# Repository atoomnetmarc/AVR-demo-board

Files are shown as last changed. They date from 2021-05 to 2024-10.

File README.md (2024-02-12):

# AT90S1200

Demo board for the 20-pin AT90S1200 and AT90S2313 microcontroller.

Yes these chips are old, Arduino was not a thing back then. The AT90S1200 on the pcb is my first microcontroller I bought and programmed. It has a date code of 1998 week 40. I wrote software for it using AVR studio (4?) in assembler and programmed it using the [Handyman programmer and software made by Elektor](https://www.elektormagazine.com/magazine/elektor-199712/33974).

This AT90S1200 has only ever been used in breadboards, now about 20 years later it got its own PCB.

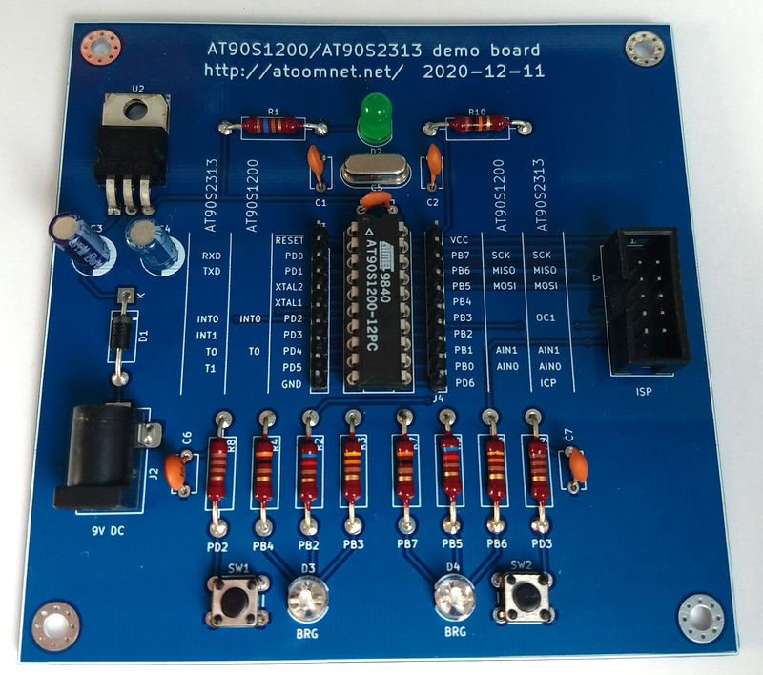
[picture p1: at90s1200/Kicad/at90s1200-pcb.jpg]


Like the silkscreen pinout? [Here](AVR%20overview.md) is a complete(-ish) overview of all know pin-compatible AT90S* microcontrollers and their pin functions.

# AT90S2323

The AT90S2323 is a 8-pin microcontroller with a whopping 3 I/O-pins. I believe this is the first 8-pin AVR.

One day I found some on eBay, bought them and proceeded to created this demo board to show its capabilities. I figured to control 128 LEDs with 3 I/O-pins. To expand de 3 I/O to drive 128 LEDs I used 3 shift registers in a 16x8 configuration. The shift registers however need 4 signals to drive them: DATA, CLK, RCLK and OE. When I tied RCLK and OE together I could bring that down to 3.

https://user-images.githubusercontent.com/48124268/116798381-1cadf400-aaef-11eb-9674-959b9dbc6236.mp4

# AT90S8535

The AT90S8535 belongs to the first 40-pin AVR microcontrollers from Atmel together with the AT90S8515. There also existed a 4K flash version of this chip, but that version seems to be only short lived, if at all.

This board breaks out all pins of the microcontroller into mostly PMOD compatible connectors. Mostly because if I understand correctly the voltage for PMOD IO and VCC should normally be at 3.3V. This board has both 5V and 3.3V PMOD connectors.

All pin-compatible microcontrollers will fit. When using a ATmega163 or newer, J8 is useable as a 5V I2C PMOD connector. When using a ATmega8535, J5 can be used as a 3.3V HW SPI PMOD port. When using ATmega323 or newer, EXP can be used as a JTAG connector.

On the back of the PCB there is a SOT-23 voltage monitor that functions as a BOD (brow out detector). Unlike newer parts, the AT90S8535 does not have a onboard BOD.

More information about this board: [README.md](at90s8535/README.md)

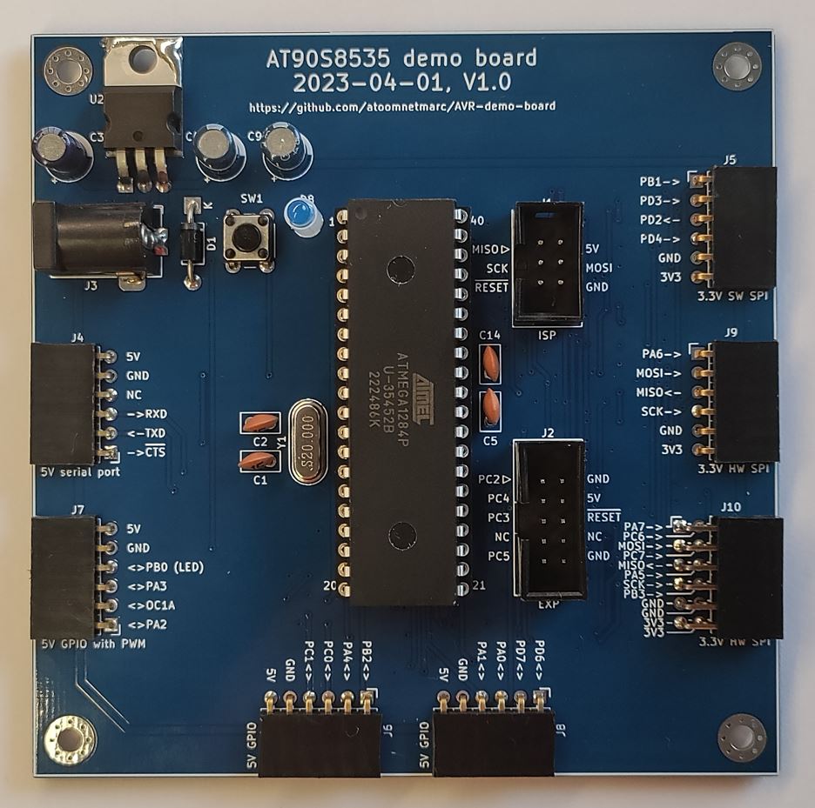
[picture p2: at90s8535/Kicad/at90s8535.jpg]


# Programming vintage AVRs in 2023

## Programmer

Make a [Arduino-as-ISP-shield](https://github.com/atoomnetmarc/Arduino-as-ISP-shield), then use AVRDUDE or [AVRDUDESS](https://blog.zakkemble.net/avrdudess-a-gui-for-avrdude/) to program the .hex file. This works under Windows 10.

AVRDUDE 6.3 is unable to program the AT90S2323 because it wrongly assumes this chip is the same as a AT90S2343, but it is not. Edit avrdude.conf and add the contents of [avrdude-at90s2323.conf](avrdude-at90s2323.conf) to just below the AT90S2343 config. This new section is a copy of the AT90S2343 section with one change, the chip signature.

## AVR Studio 4.19

Use the ancient [AVR Studio v4.19.730](https://www.microchip.com/mplab/avr-support/avr-and-sam-downloads-archive) to compile programs for the old AT90S* AVR's.

To compile c-programs you can still use [WinAVR-20100110-install.exe](https://sourceforge.net/projects/winavr/files/WinAVR/20100110/) containing ~~an old~~ a mature GCC compiler versioned 4.3, but you need some to [fix some incompatibilities with Windows 10](https://www.avrfreaks.net/s/topic/a5C3l000000USrIEAW/t124726) in order to make it work.\
There is a simpler solution, just use an [updated GCC](https://blog.zakkemble.net/avr-gcc-builds/). This update contains GCC version 12 and works to compile programs for the old AT90S* chips in AVR Studio 4.19.

## Visual Studio Code + PlatformIO

I was pleasantly surprised to find out that compiling a c-program using VSCode and PlatformIO also is a viable option. See the firmware directory of the AT90S2323 for an example on how to configure PlatformIO or see [the PlatformIO example native-blink](https://github.com/platformio/platform-atmelavr/tree/develop/examples/native-blink).

It is also possible to program the AT90S1200 in VSCode with PlatformIO in assembler! Have a look at my PlatformIO [blink](at90s1200/Firmware/blink/) project. You could also program the ATtiny2313 with the same assembler (and some `#if defined` macros) and debug using Microchip Studio.



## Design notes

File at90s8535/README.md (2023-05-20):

# MightyCore

You could use [MightyCore](https://github.com/MCUdude/MightyCore) to program a supported MCU (ATmega8535, ATmega16, ATmega32, ATmega164, ATmega324, ATmega644 and ATmega1284) using Arduino IDE or PlatformIO.

To be useful as an Arduino board, you must first burn a bootloader using the Arduino IDE. Use the instructions from the [MightyCore GitHub page](https://github.com/MCUdude/MightyCore) to burn the bootloader.

Verify the bootloader burn by compiling the blink sketch and uploading it to the board using the [USB UART PMOD](https://github.com/atoomnetmarc/PMOD-USB-UART) (or your own compatible serial cable). After uploading LED D8 should blink.

# AT90S4434 or AT90S8535

These old MCUs do not have bootloader capability and are not supported by [MightyCore](https://github.com/MCUdude/MightyCore). Program these with a AVR programmer connected to the ISP header.

# ATmega163 or ATmega323

The ATmega163 and ATmega323 are also not supported by [MightyCore](https://github.com/MCUdude/MightyCore). These MCUs do contain bootloader capability but are not supported by [Optiboot](https://github.com/Optiboot/optiboot).

At this moment (2023-05) you can program these just like the AT90S8535 using the ISP header.

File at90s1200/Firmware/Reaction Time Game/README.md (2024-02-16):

# Reaction Time Game

2 players battle for the fastest reaction time. Game automatically starts when MCU is powered on. Players must press button when blue LED turn off. This will happen after a random amount of time.

The fastest reaction time is indicated by a few seconds of green LED. Slowest reaction time is indicated by red LED. When somehow both players are equally fast, because buttons are samples 1000 times a second, then both get green LED. When no reaction was given, both get red LED. Pressed too early? Red.

Randomness is generated when a button is pressed.

State machine:\


This game was specifically written in gcc assembly for the RAM-less AT90S1200, but also made working on pin-compatible newer AVR parts.

| MCU | tested? |
| -- | -- |
| AT90S1200 | :ballot_box_with_check: |
| AT90S2313 | :ballot_box_with_check: |
| ATtiny2313 | :ballot_box_with_check: |
| ATtiny2313A | :black_square_button: |
| ATtiny4313 | :black_square_button: |



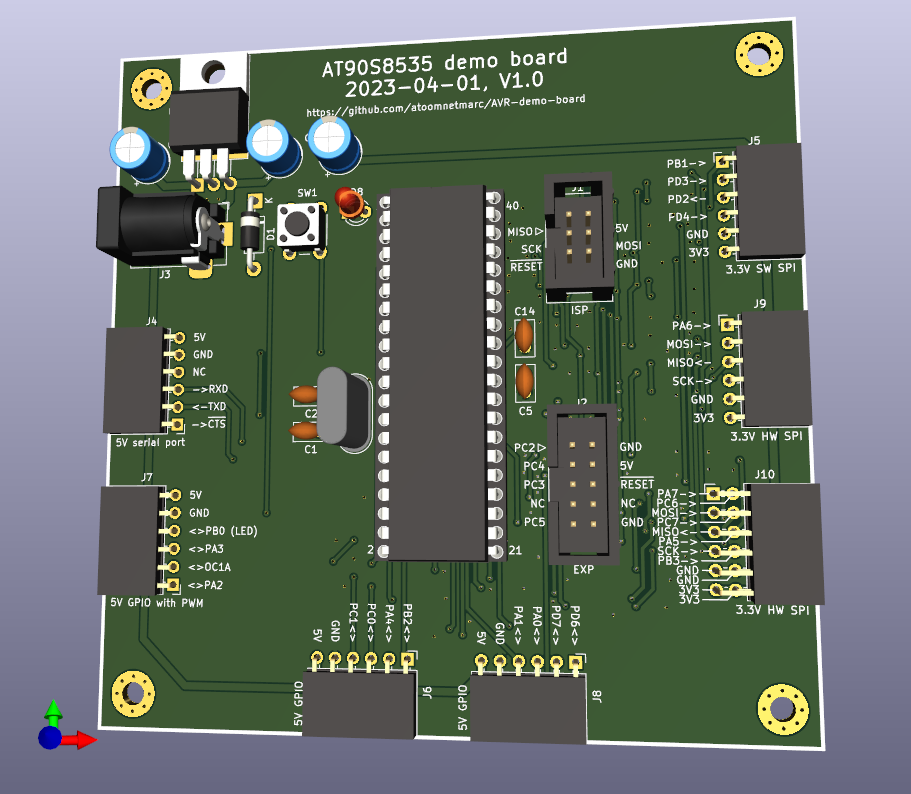
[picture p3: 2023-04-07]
at90s8535/Kicad/at90s8535-render.png

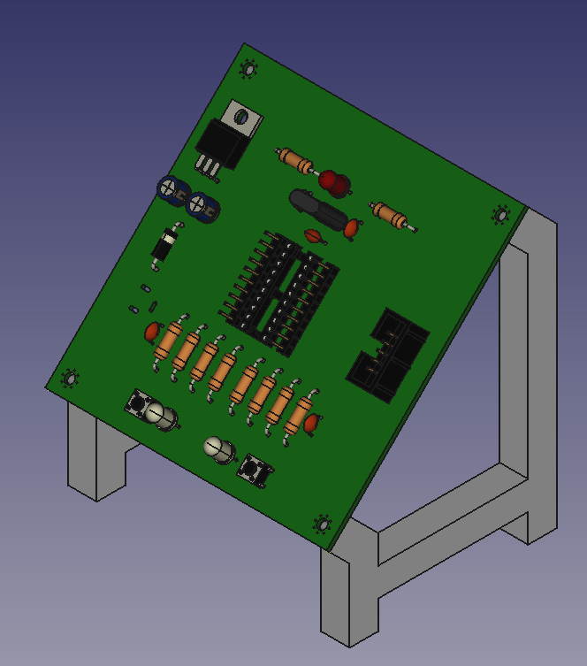
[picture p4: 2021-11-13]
at90s1200/3d/presentation stand.png

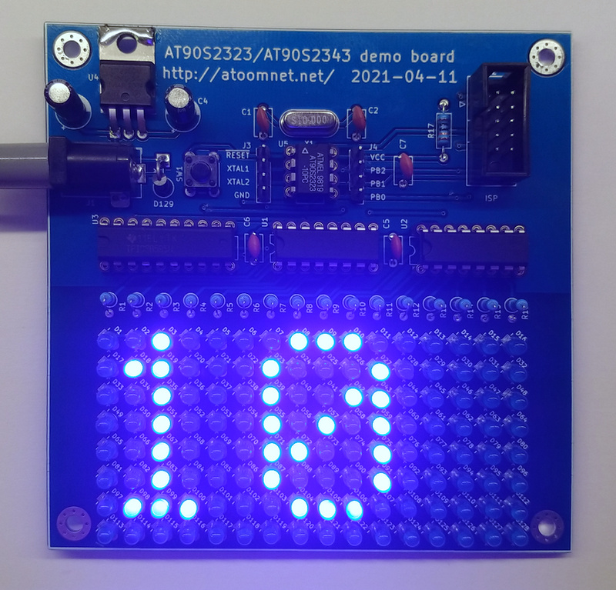
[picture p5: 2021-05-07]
at90s2323/Kicad/at90s2323-pcb.jpg

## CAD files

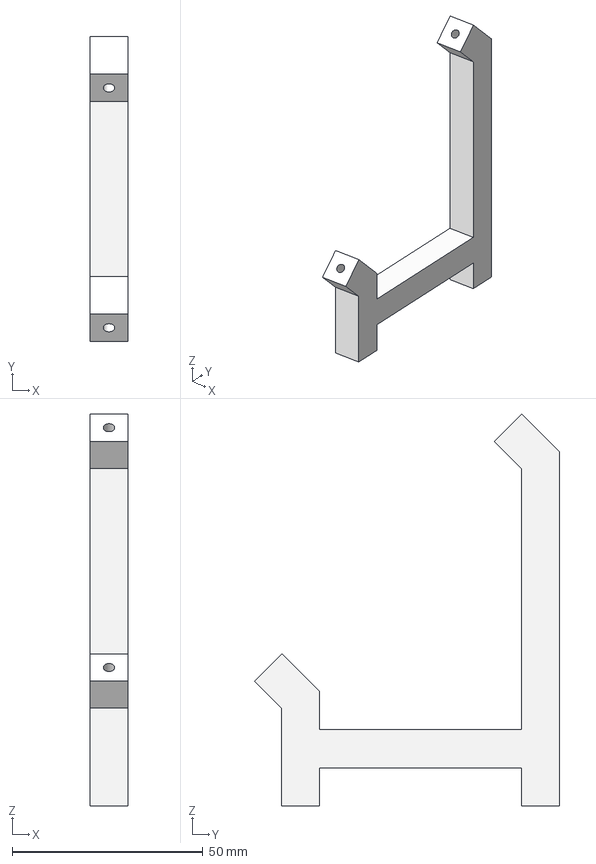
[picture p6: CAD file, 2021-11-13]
at90s1200/3d/presentation stand.step
10.0 x 79.9 x 102.7 mm

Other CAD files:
at90s1200/3d/presentation stand.FCStd
at90s1200/3d/presentation stand.stl

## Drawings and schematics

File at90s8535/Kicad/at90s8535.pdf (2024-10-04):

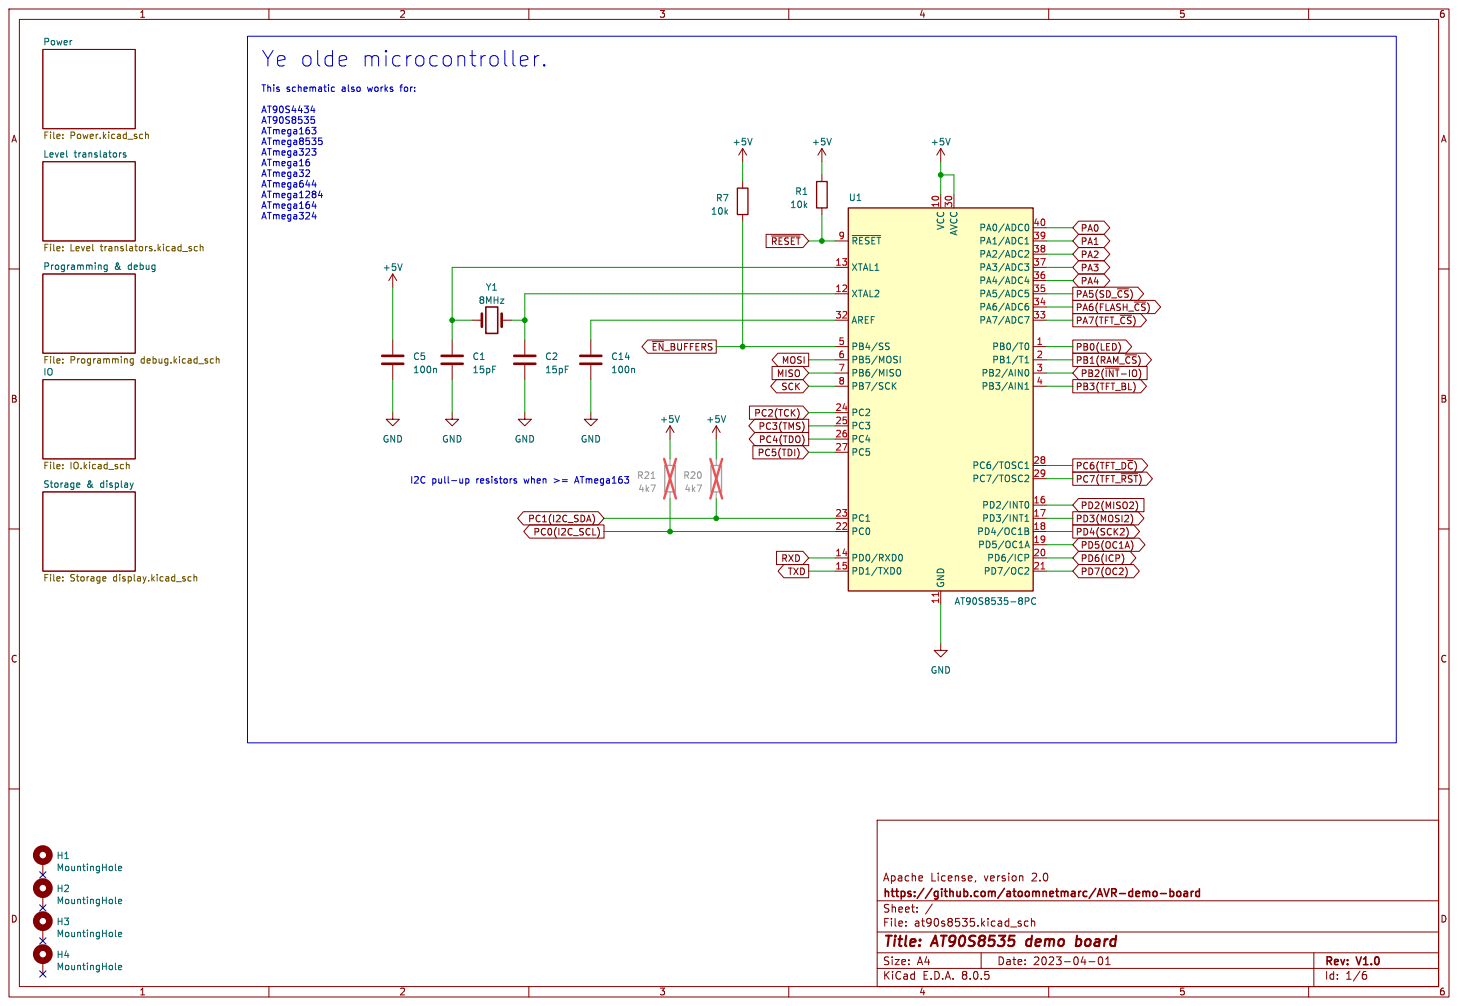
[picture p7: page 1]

PA6(FLASH_~{CS}) TXD Ye olde microcontroller.

Storage & display File: Storage display.kicad_sch

H2 MountingHole H3 MountingHole H1 MountingHole H4 MountingHole

Apache License, version 2.0
File: at90s8535.kicad_sch Sheet: / https://github.com/atoomnetmarc/AVR-demo-board

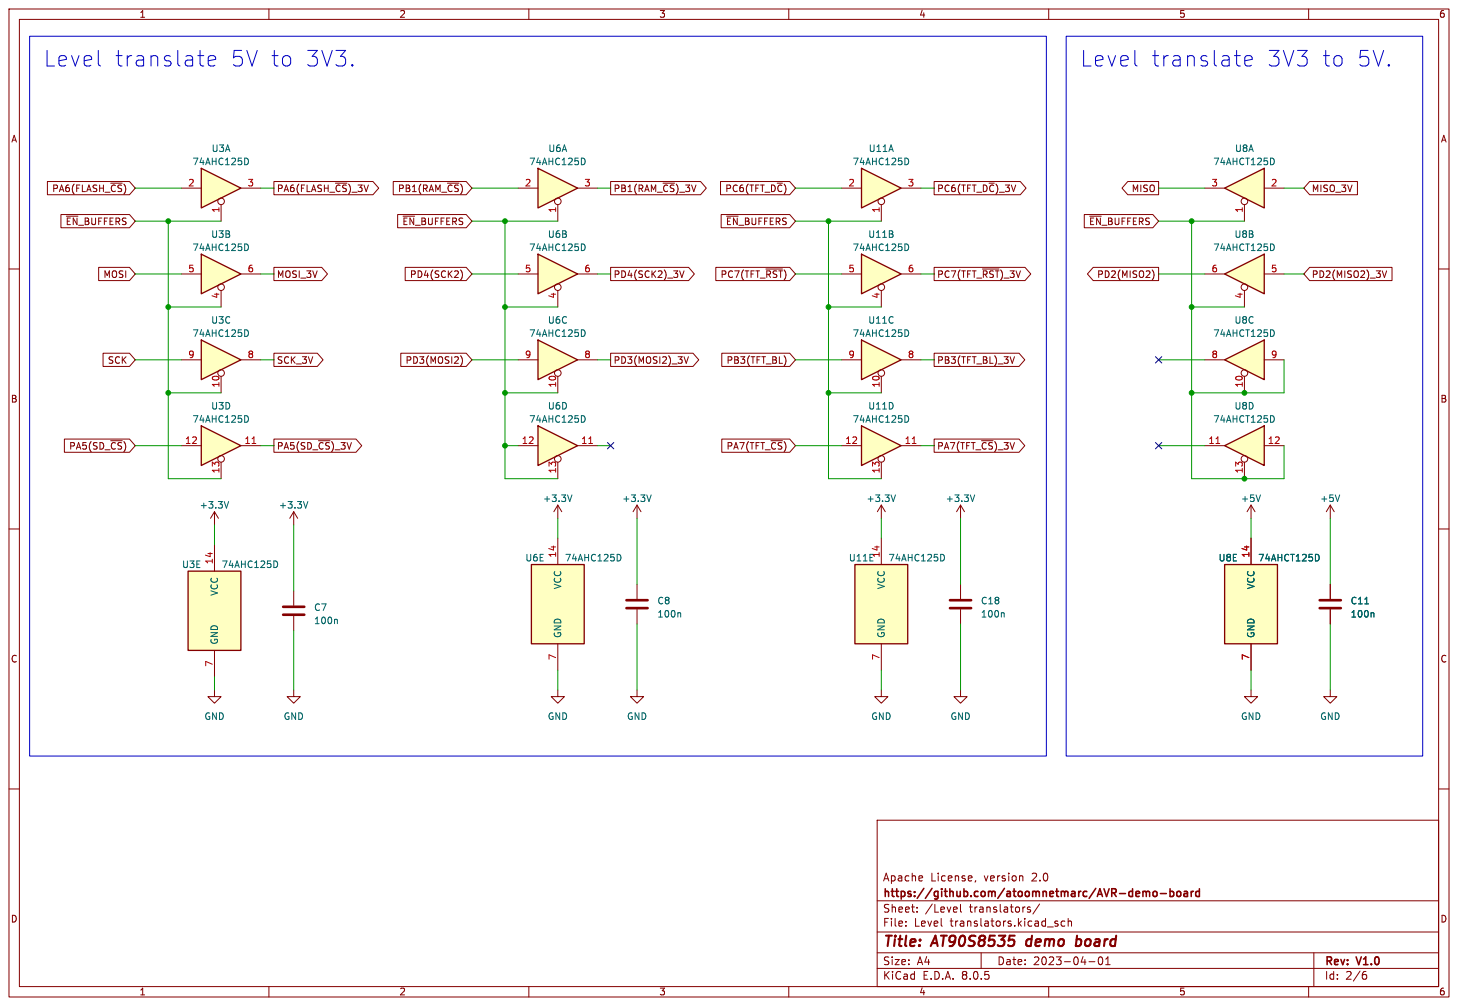
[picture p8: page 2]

Apache License, version 2.0 GND VCC 14 GND

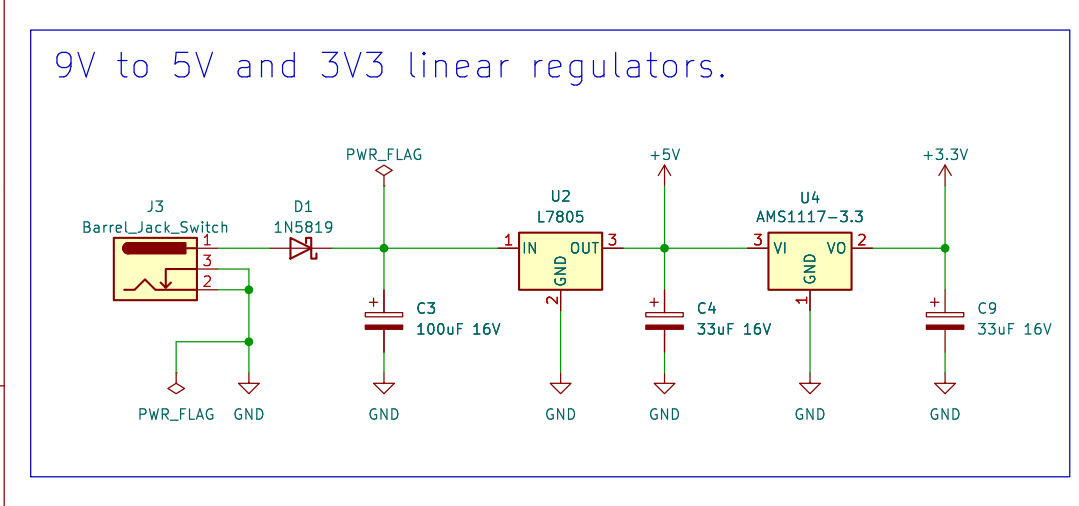
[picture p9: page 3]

1 VO 2 VI 3 U4 AMS1117-3.3 PWR_FLAG +3.3V GND GND

Apache License, version 2.0
File: Power.kicad_sch Sheet: /Power/ https://github.com/atoomnetmarc/AVR-demo-board

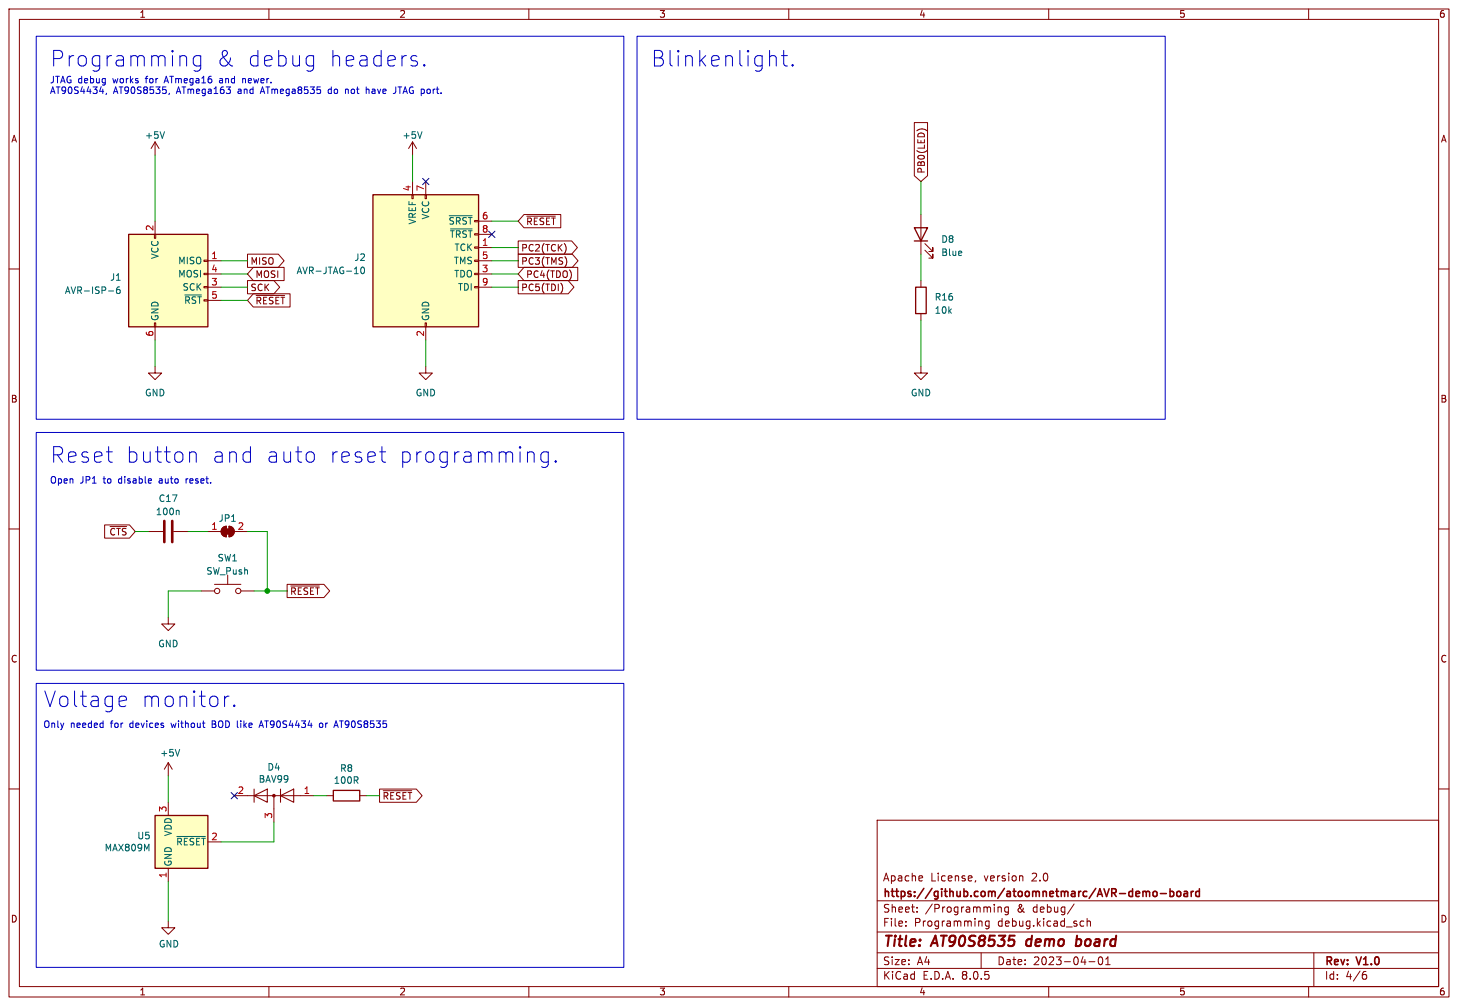
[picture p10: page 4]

2 SCK 3 MOSI 4 ~{RST}5 GND

Open JP1 to disable auto reset.

Only needed for devices without BOD like AT90S4434 or AT90S8535

Apache License, version 2.0
https://github.com/atoomnetmarc/AVR-demo-board

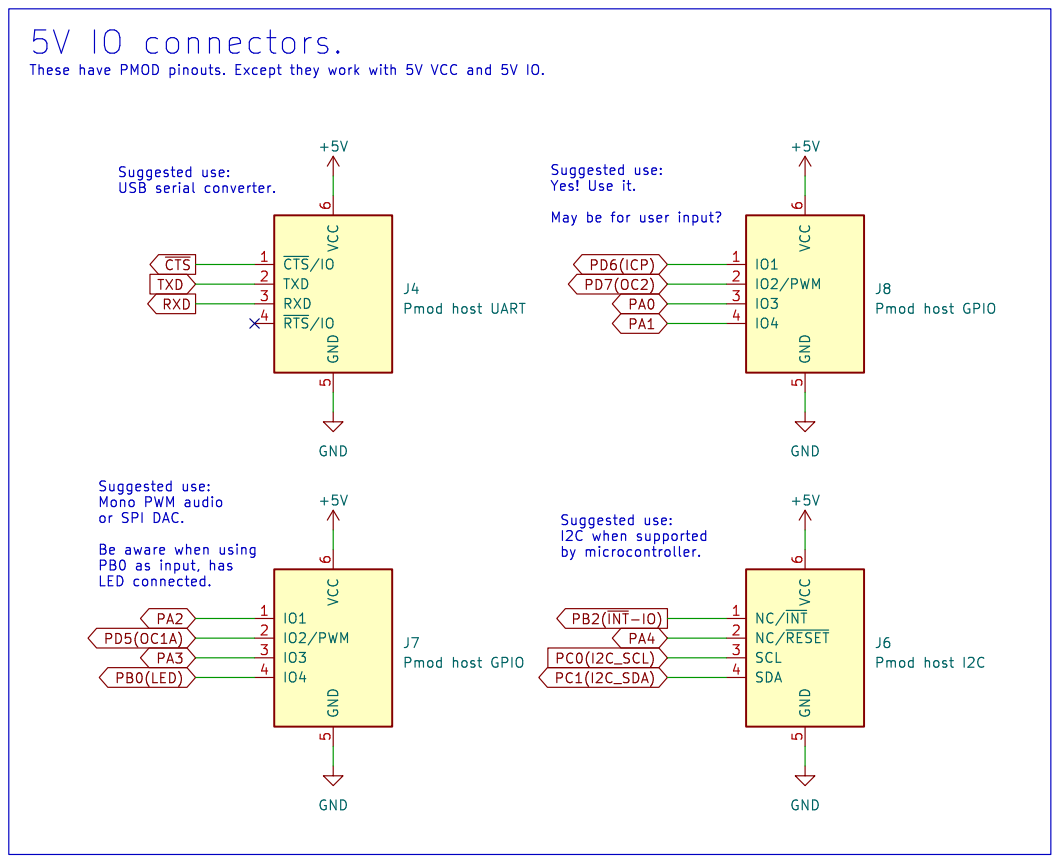
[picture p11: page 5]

Suggested use: Yes! Use it. May be for user input?

Suggested use: Mono PWM audio

Apache License, version 2.0
File: IO.kicad_sch Sheet: /IO/ https://github.com/atoomnetmarc/AVR-demo-board

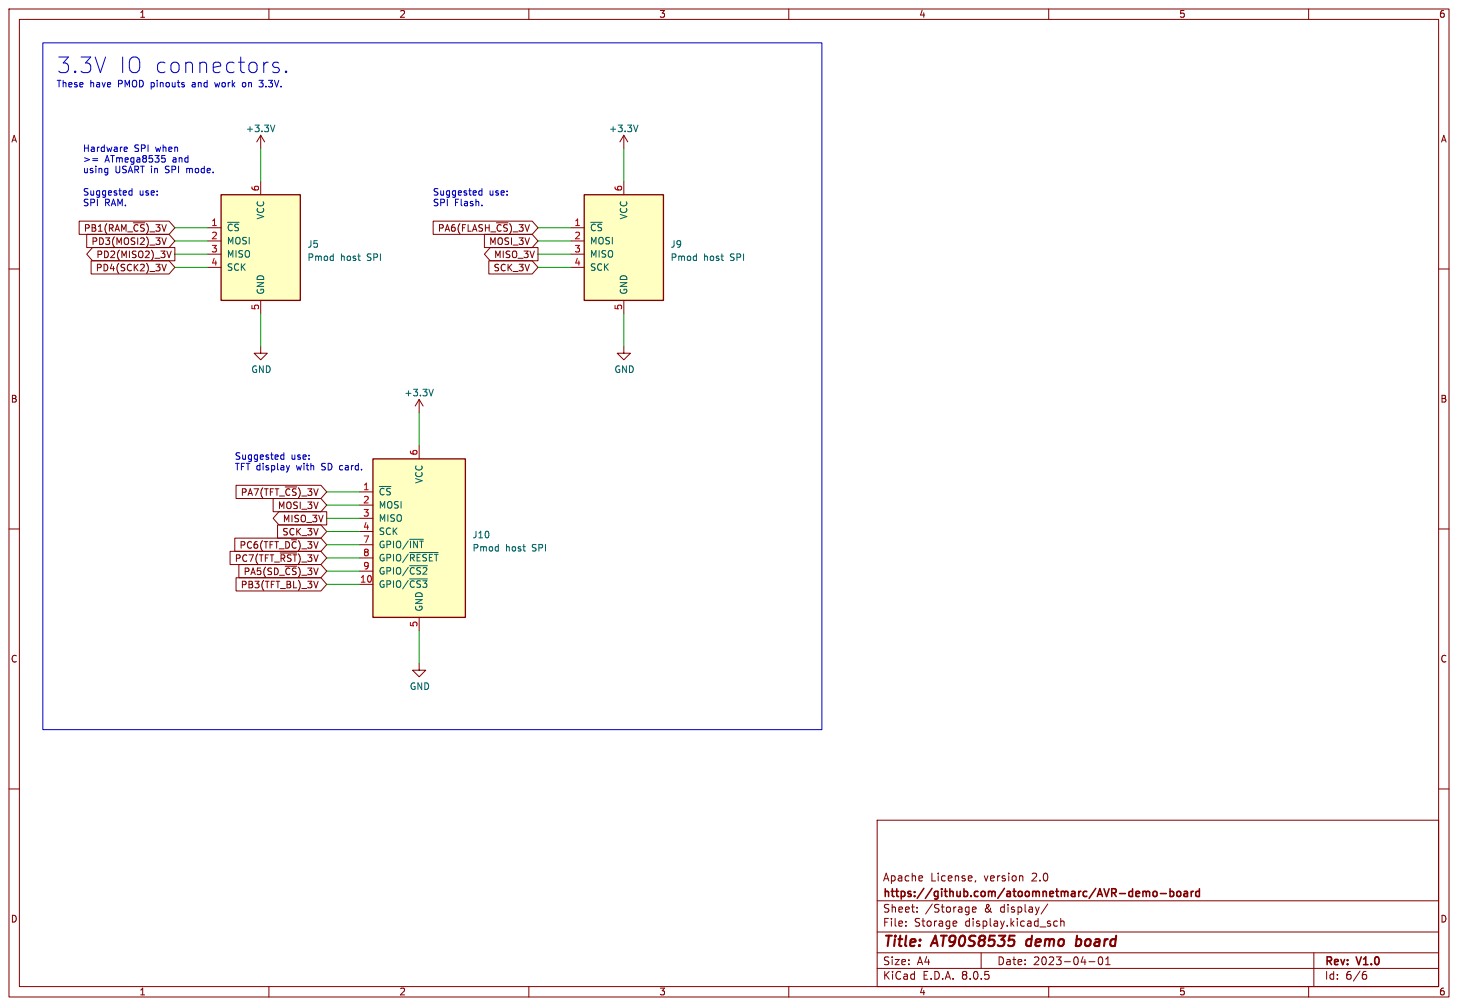
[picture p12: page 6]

using USART in SPI mode. 3.3V IO connectors.

6 GPIO/~{INT} 7 GPIO/~{RESET} 8 GPIO/~{CS2} 9

Apache License, version 2.0
https://github.com/atoomnetmarc/AVR-demo-board

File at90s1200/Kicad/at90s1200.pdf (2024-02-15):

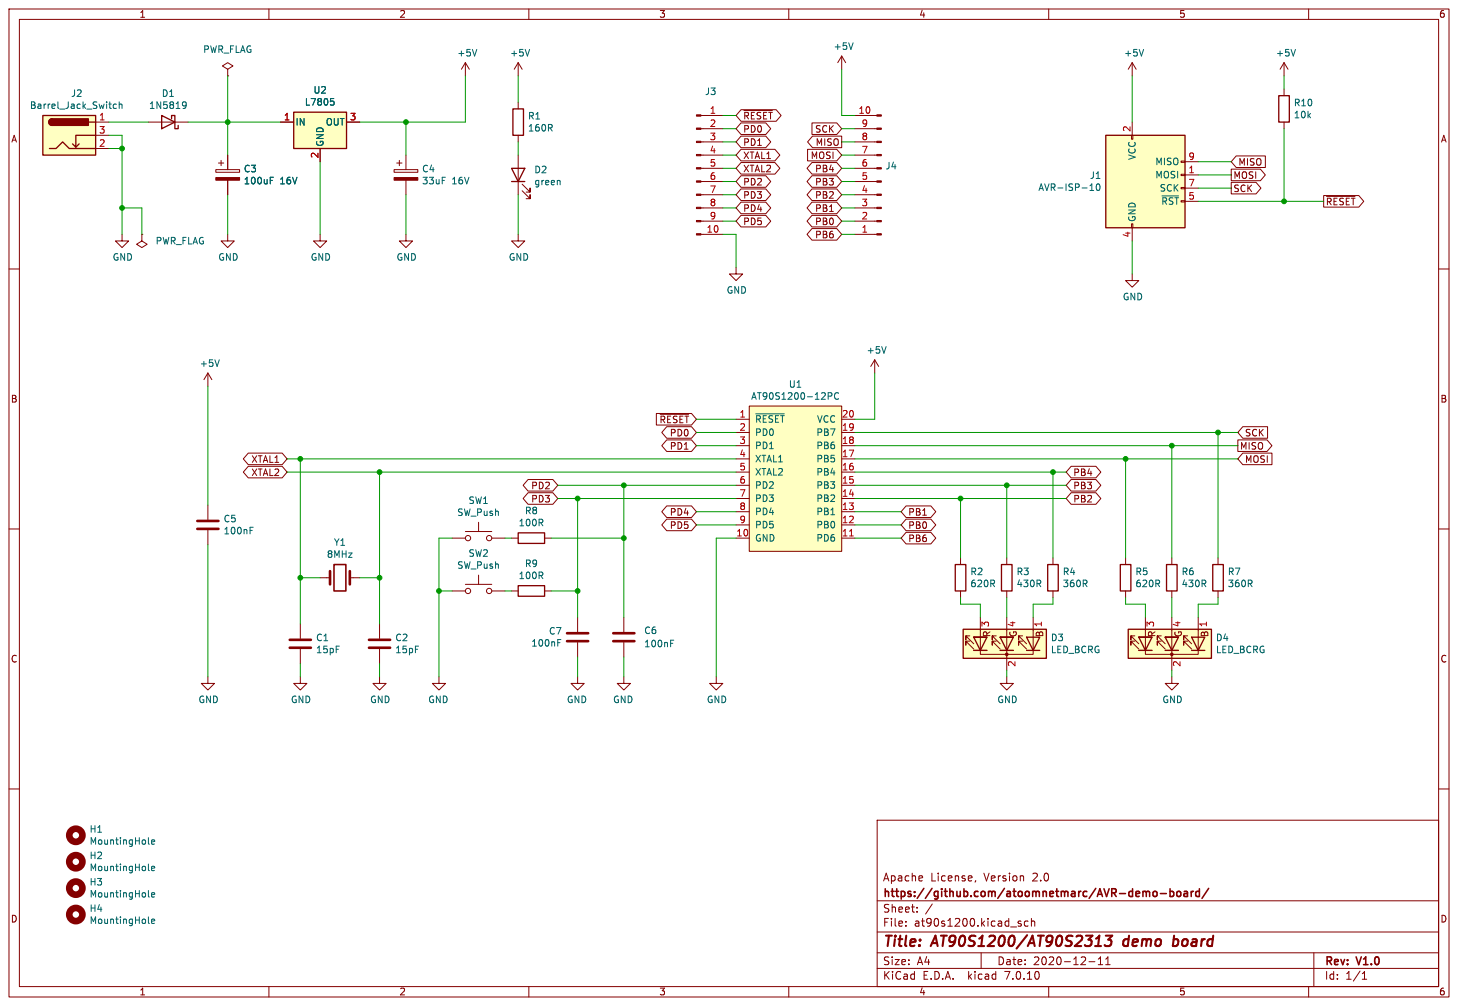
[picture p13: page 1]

Apache License, Version 2.0
File: at90s1200.kicad_sch Sheet: / https://github.com/atoomnetmarc/AVR-demo-board/

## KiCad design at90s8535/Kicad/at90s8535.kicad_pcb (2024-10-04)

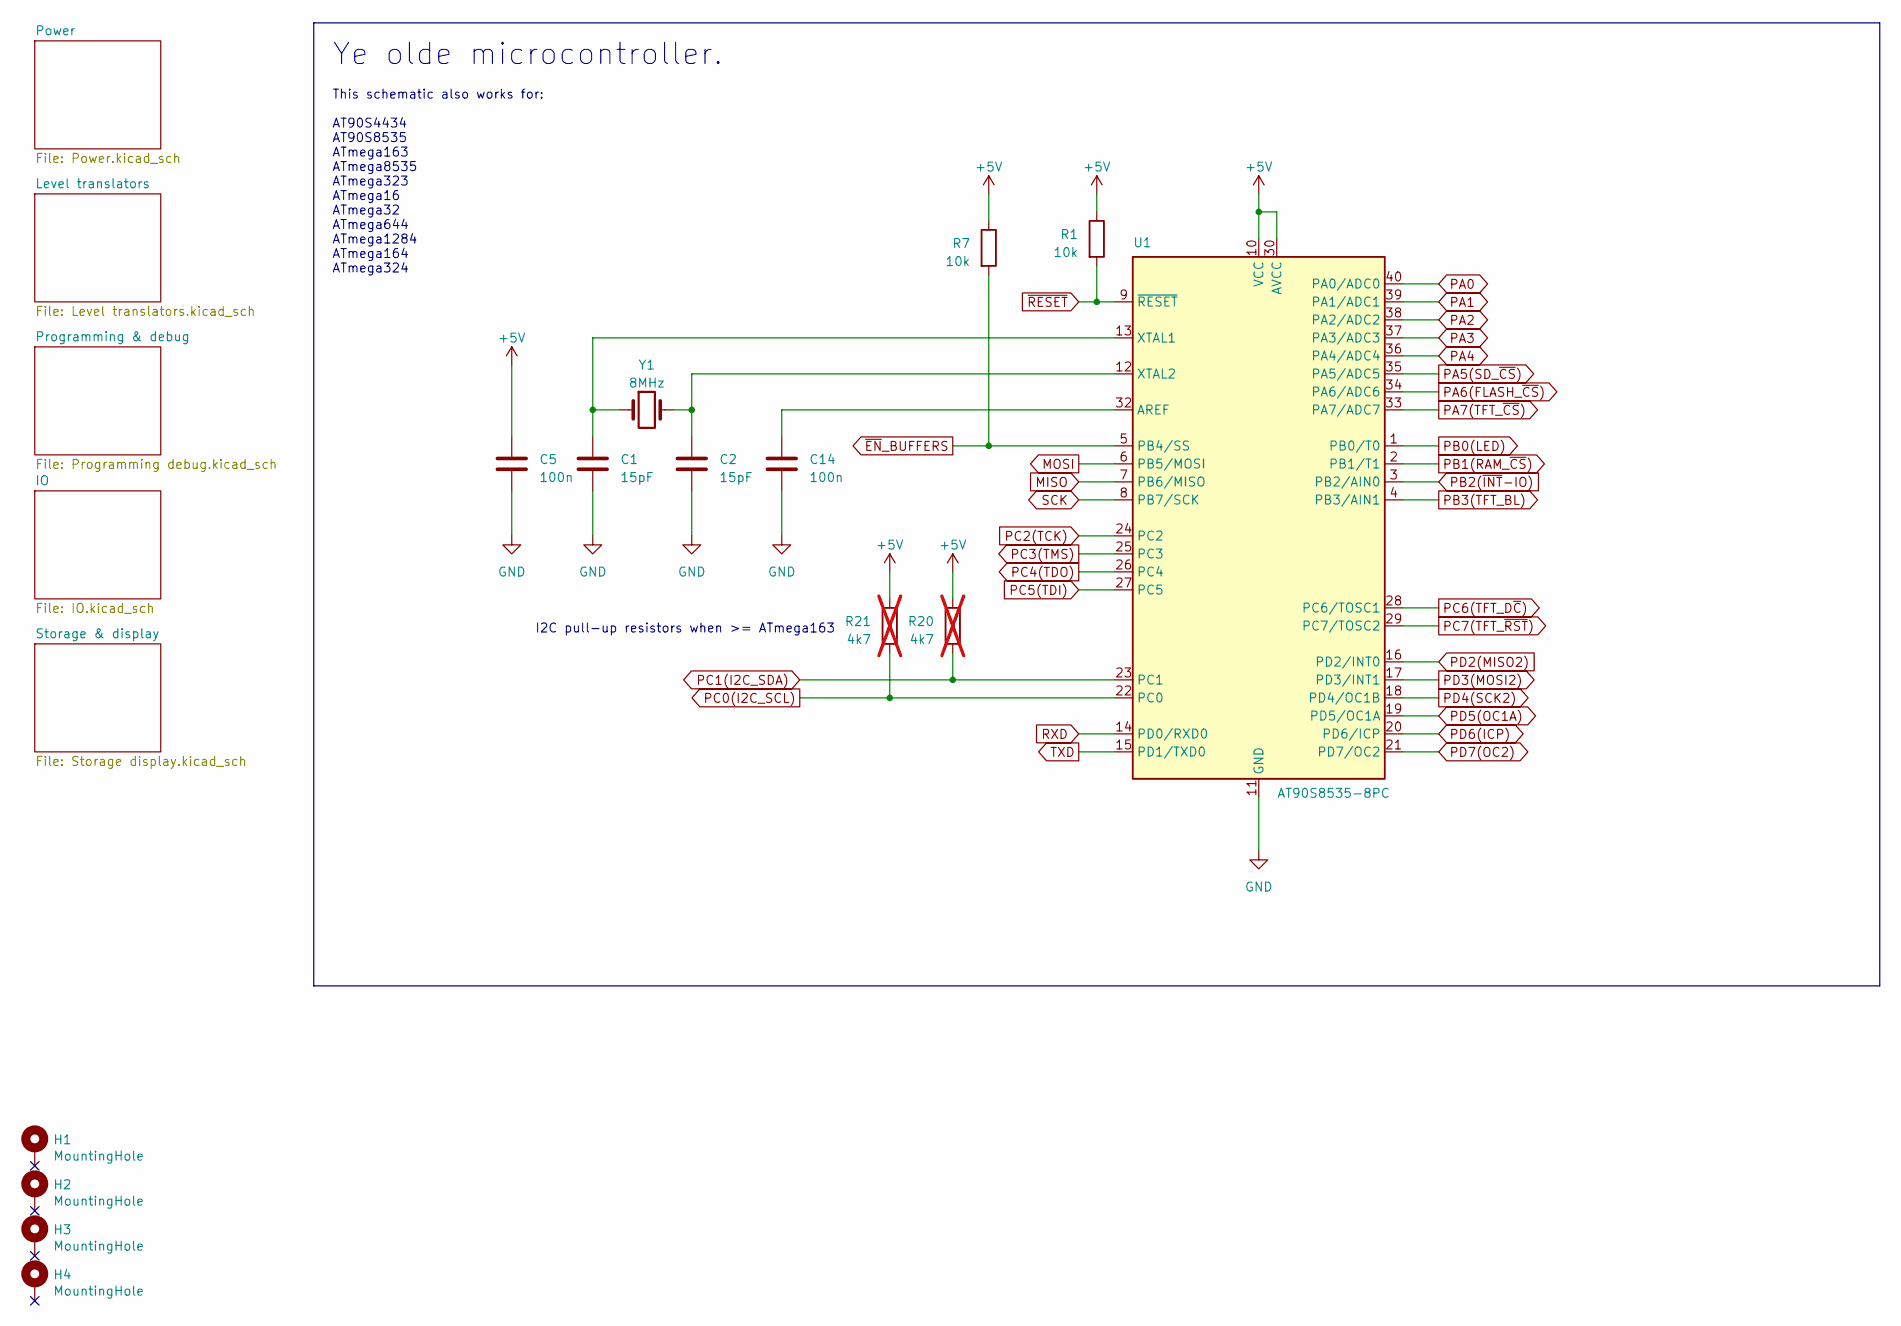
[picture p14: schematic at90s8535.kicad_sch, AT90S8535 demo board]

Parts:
C1, C2: 15pF; C_Disc_D5.0mm_W2.5mm_P2.50mm
C5, C14: 100n; C_Disc_D5.0mm_W2.5mm_P2.50mm
H1, H2, H3, H4: MountingHole; MountingHole_3.2mm_M3_Pad_Via
R1, R7: 10k; R_0805_2012Metric_Pad1.20x1.40mm_HandSolder
R20, R21: 4k7; R_0805_2012Metric_Pad1.20x1.40mm_HandSolder; not fitted
U1: AT90S8535-8PC; DIP-40_W15.24mm
Y1: 8MHz; Crystal_HC49-U_Vertical

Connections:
MISO: U1.7 (PB6/MISO); also elsewhere on the board
MOSI: U1.6 (PB5/MOSI); also elsewhere on the board
unnamed: C14.1, U1.32 (AREF)
unnamed: C1.1, U1.13 (XTAL1), Y1.1
unnamed: C2.1, U1.12 (XTAL2), Y1.2
PA0: U1.40 (PA0/ADC0); also elsewhere on the board
PA1: U1.39 (PA1/ADC1); also elsewhere on the board
PA2: U1.38 (PA2/ADC2); also elsewhere on the board
PA3: U1.37 (PA3/ADC3); also elsewhere on the board
PA4: U1.36 (PA4/ADC4); also elsewhere on the board
PA5(SD_~CS): U1.35 (PA5/ADC5); also elsewhere on the board
PA6(FLASH_~CS): U1.34 (PA6/ADC6); also elsewhere on the board
PA7(TFT_~CS): U1.33 (PA7/ADC7); also elsewhere on the board
PB0(LED): U1.1 (PB0/T0); also elsewhere on the board
PB2(~INT-IO): U1.3 (PB2/AIN0); also elsewhere on the board
PB3(TFT_BL): U1.4 (PB3/AIN1); also elsewhere on the board
PC0(I2C_SCL): R21.2, U1.22 (PC0); also elsewhere on the board
PC1(I2C_SDA): R20.2, U1.23 (PC1); also elsewhere on the board
PC2(TCK): U1.24 (PC2); also elsewhere on the board
PC3(TMS): U1.25 (PC3); also elsewhere on the board
PC4(TDO): U1.26 (PC4); also elsewhere on the board
PC5(TDI): U1.27 (PC5); also elsewhere on the board
PC6(TFT_D~C): U1.28 (PC6/TOSC1); also elsewhere on the board
PC7(TFT_~RST): U1.29 (PC7/TOSC2); also elsewhere on the board
PD2(MISO2): U1.16 (PD2/INT0); also elsewhere on the board
PD3(MOSI2): U1.17 (PD3/INT1); also elsewhere on the board
PD4(SCK2): U1.18 (PD4/OC1B); also elsewhere on the board
PD5(OC1A): U1.19 (PD5/OC1A); also elsewhere on the board
PD6(ICP): U1.20 (PD6/ICP); also elsewhere on the board
PD7(OC2): U1.21 (PD7/OC2); also elsewhere on the board
RXD: U1.14 (PD0/RXD0); also elsewhere on the board
SCK: U1.8 (PB7/SCK); also elsewhere on the board
TXD: U1.15 (PD1/TXD0); also elsewhere on the board
~RESET: R1.2, U1.9 (~RESET); also elsewhere on the board

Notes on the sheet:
I2C pull-up resistors when >= ATmega163
Ye olde microcontroller.
This schematic also works for: AT90S4434 AT90S8535 ATmega163 ATmega8535 ATmega323 ATmega16 ATmega32 ATmega644 ATmega1284 ATmega164 ATmega324

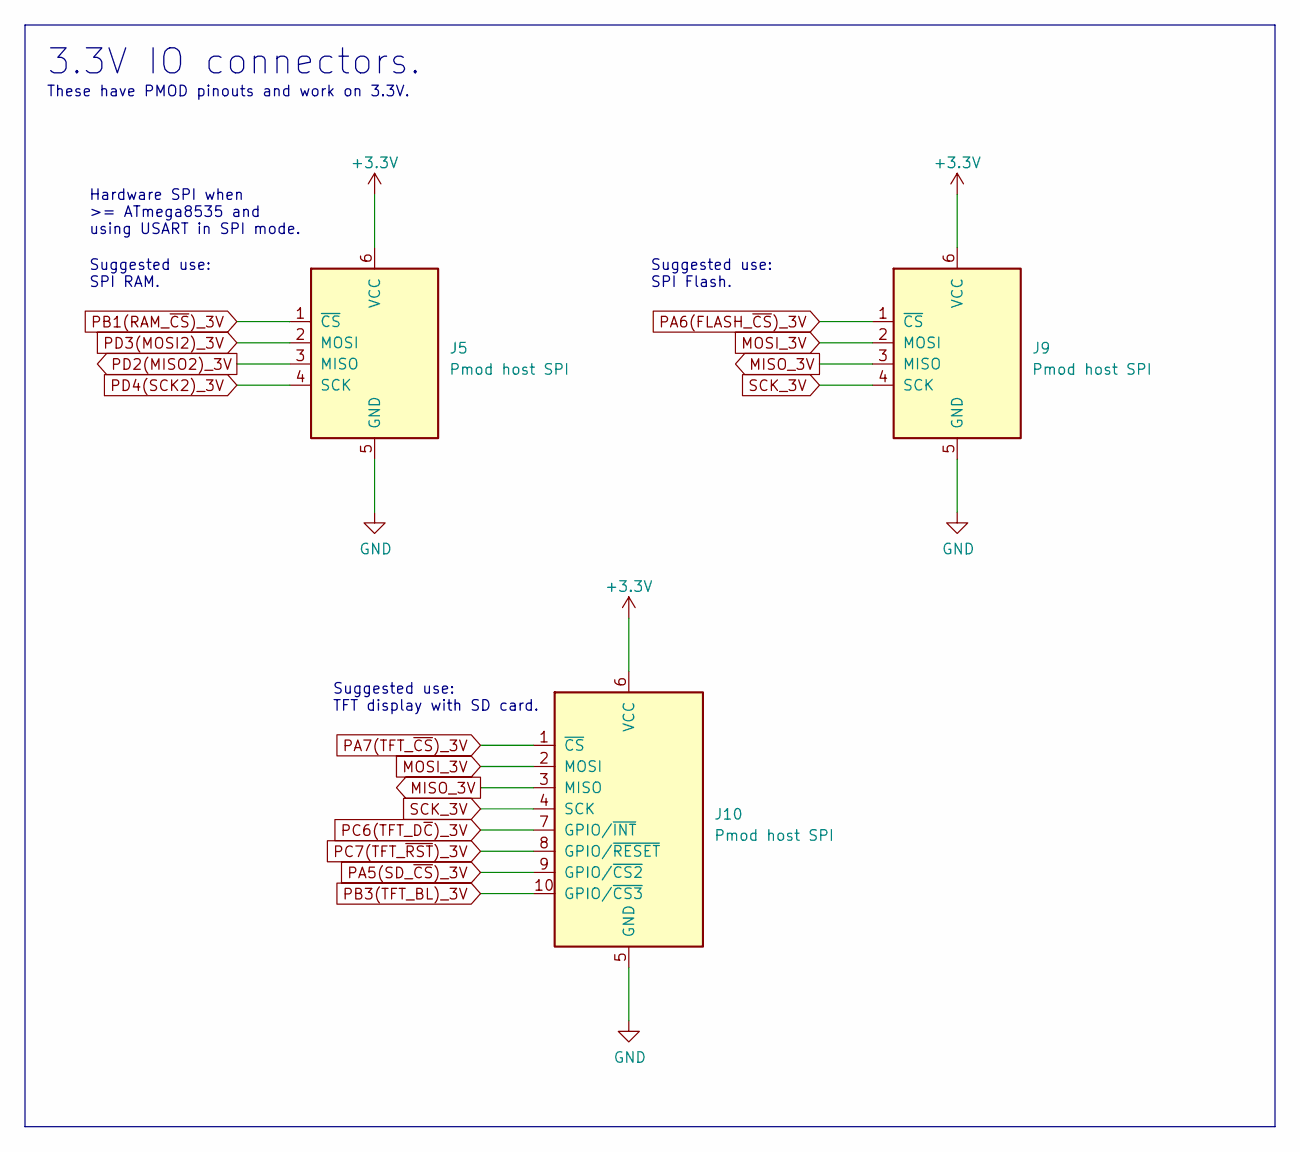
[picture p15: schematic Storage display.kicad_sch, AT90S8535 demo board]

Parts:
J5, J9: Pmod host SPI; PinSocket_1x06_P2.54mm_Horizontal
J10: Pmod host SPI; PinSocket_2x06_P2.54mm_Horizontal_Top_Bottom

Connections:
+3.3V: J5.6 (VCC), J9.6 (VCC), J10.6 (VCC), J10.12 (VCC); also elsewhere on the board
MISO_3V: J9.3 (MISO), J10.3 (MISO); also elsewhere on the board
MOSI_3V: J9.2 (MOSI), J10.2 (MOSI); also elsewhere on the board
PA5(SD_~CS)_3V: J10.9 (GPIO/~CS2); also elsewhere on the board
PA6(FLASH_~CS)_3V: J9.1 (~CS); also elsewhere on the board
PA7(TFT_~CS)_3V: J10.1 (~CS); also elsewhere on the board
PB3(TFT_BL)_3V: J10.10 (GPIO/~CS3); also elsewhere on the board
PC6(TFT_D~C)_3V: J10.7 (GPIO/~INT); also elsewhere on the board
PC7(TFT_~RST)_3V: J10.8 (GPIO/~RESET); also elsewhere on the board
PD2(MISO2)_3V: J5.3 (MISO); also elsewhere on the board
PD3(MOSI2)_3V: J5.2 (MOSI); also elsewhere on the board
PD4(SCK2)_3V: J5.4 (SCK); also elsewhere on the board
SCK_3V: J9.4 (SCK), J10.4 (SCK); also elsewhere on the board

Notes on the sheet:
Hardware SPI when >= ATmega8535 and using USART in SPI mode.
3.3V IO connectors.
Suggested use: SPI RAM.
These have PMOD pinouts and work on 3.3V.
Suggested use: TFT display with SD card.
Suggested use: SPI Flash.

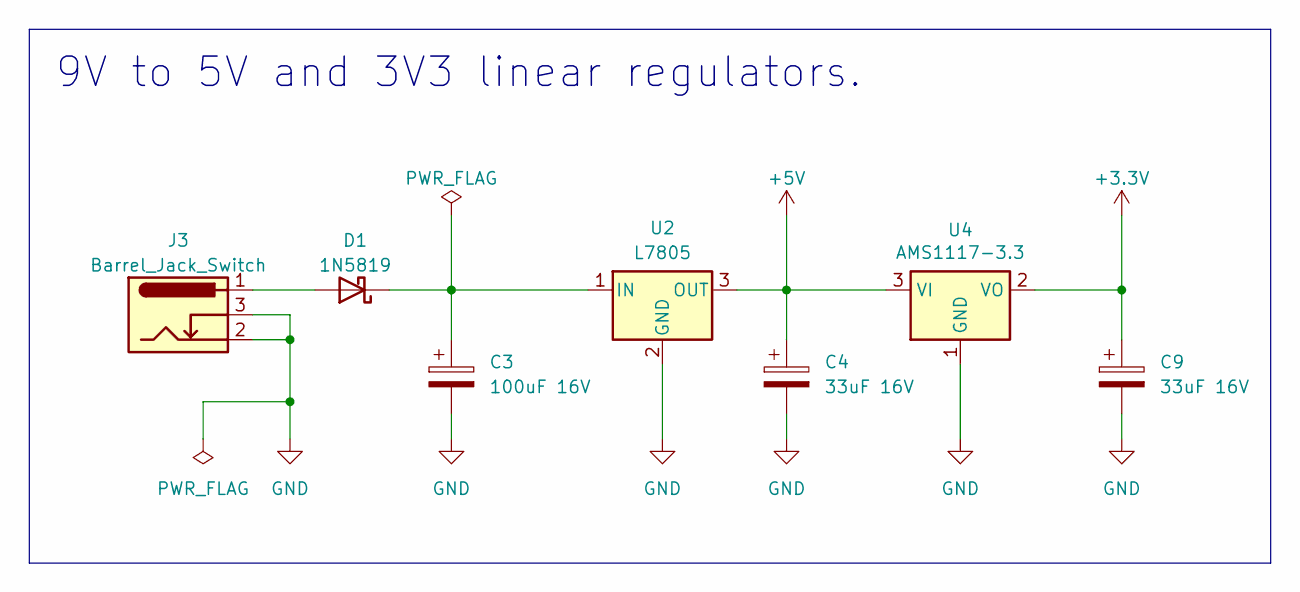
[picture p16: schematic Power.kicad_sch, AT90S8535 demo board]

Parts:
C3: 100uF 16V; CP_Radial_D6.3mm_P2.50mm
C4, C9: 33uF 16V; CP_Radial_D6.3mm_P2.50mm
D1: 1N5819; D_DO-41_SOD81_P10.16mm_Horizontal
J3: Barrel_Jack_Switch; BarrelJack_Horizontal
U2: L7805; TO-220-3_Horizontal_TabDown
U4: AMS1117-3.3; SOT-223-3_TabPin2

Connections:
+3.3V: C9.1, U4.2 (VO); also elsewhere on the board
unnamed: D1.2 (A), J3.1
unnamed: C3.1, D1.1 (K), U2.1 (IN)

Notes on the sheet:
9V to 5V and 3V3 linear regulators.

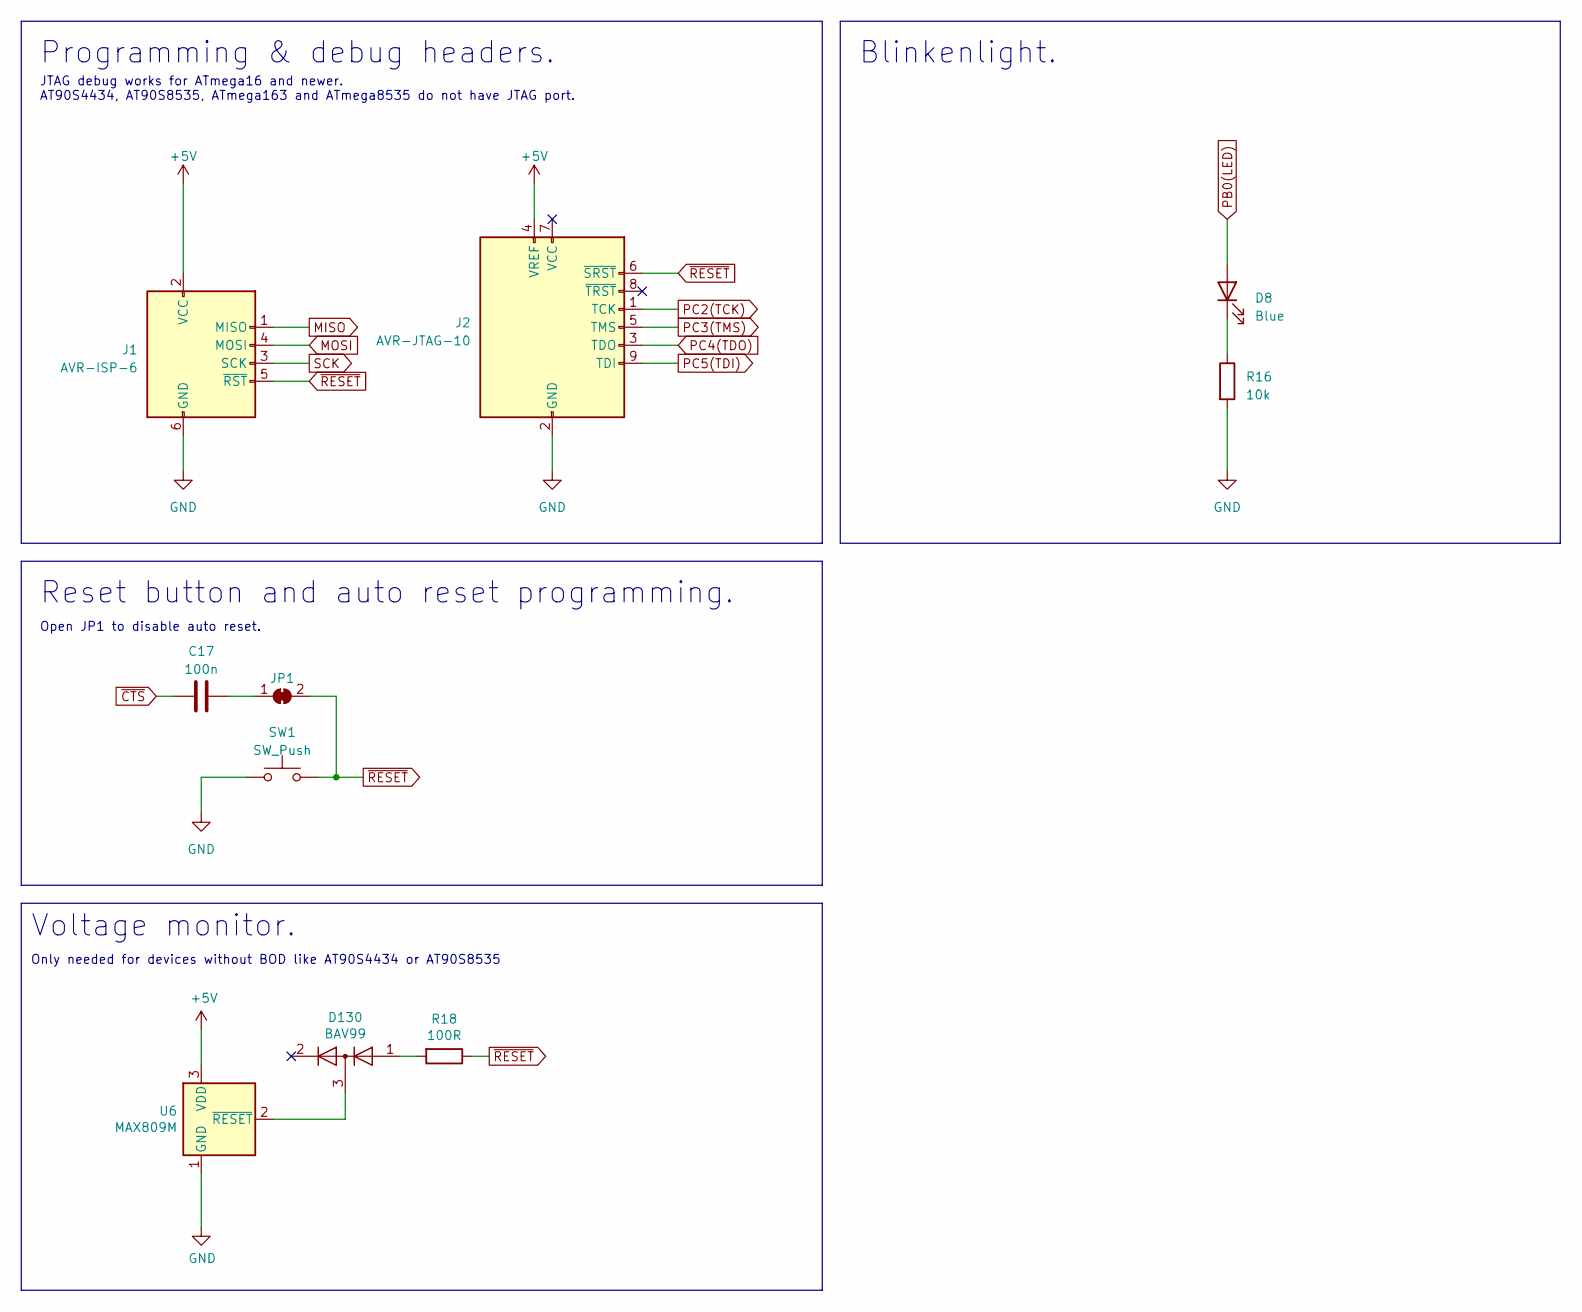
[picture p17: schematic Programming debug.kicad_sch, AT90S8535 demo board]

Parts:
C17: 100n; C_0805_2012Metric_Pad1.18x1.45mm_HandSolder
D8: Blue; LED_D3.0mm
D130: BAV99; SOT-23
J1: AVR-ISP-6; IDC-Header_2x03_P2.54mm_Vertical
J2: AVR-JTAG-10; IDC-Header_2x05_P2.54mm_Vertical
JP1: SolderJumper_2_Bridged; SolderJumper-2_P1.3mm_Bridged_RoundedPad1.0x1.5mm
R16: 10k; R_0805_2012Metric_Pad1.20x1.40mm_HandSolder
R18: 100R; R_0805_2012Metric_Pad1.20x1.40mm_HandSolder
SW1: SW_Push; SW_PUSH_6mm
U6: MAX809M; SOT-23

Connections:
MISO: J1.1 (MISO); also elsewhere on the board
MOSI: J1.4 (MOSI); also elsewhere on the board
unnamed: D8.1 (K), R16.1
unnamed: C17.2, JP1.1 (A)
PB0(LED): D8.2 (A); also elsewhere on the board
PC2(TCK): J2.1 (TCK); also elsewhere on the board
PC3(TMS): J2.5 (TMS); also elsewhere on the board
PC4(TDO): J2.3 (TDO); also elsewhere on the board
PC5(TDI): J2.9 (TDI); also elsewhere on the board
SCK: J1.3 (SCK); also elsewhere on the board
~CTS: C17.1; also elsewhere on the board
~RESET: J1.5 (~RST), J2.6 (~SRST), JP1.2 (B), SW1.2; also elsewhere on the board

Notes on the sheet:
Open JP1 to disable auto reset.
Programming & debug headers.
Reset button and auto reset programming.
Voltage monitor.
Only needed for devices without BOD like AT90S4434 or AT90S8535
Blinkenlight.
JTAG debug works for ATmega16 and newer. AT90S4434, AT90S8535, ATmega163 and ATmega8535 do not have JTAG port.

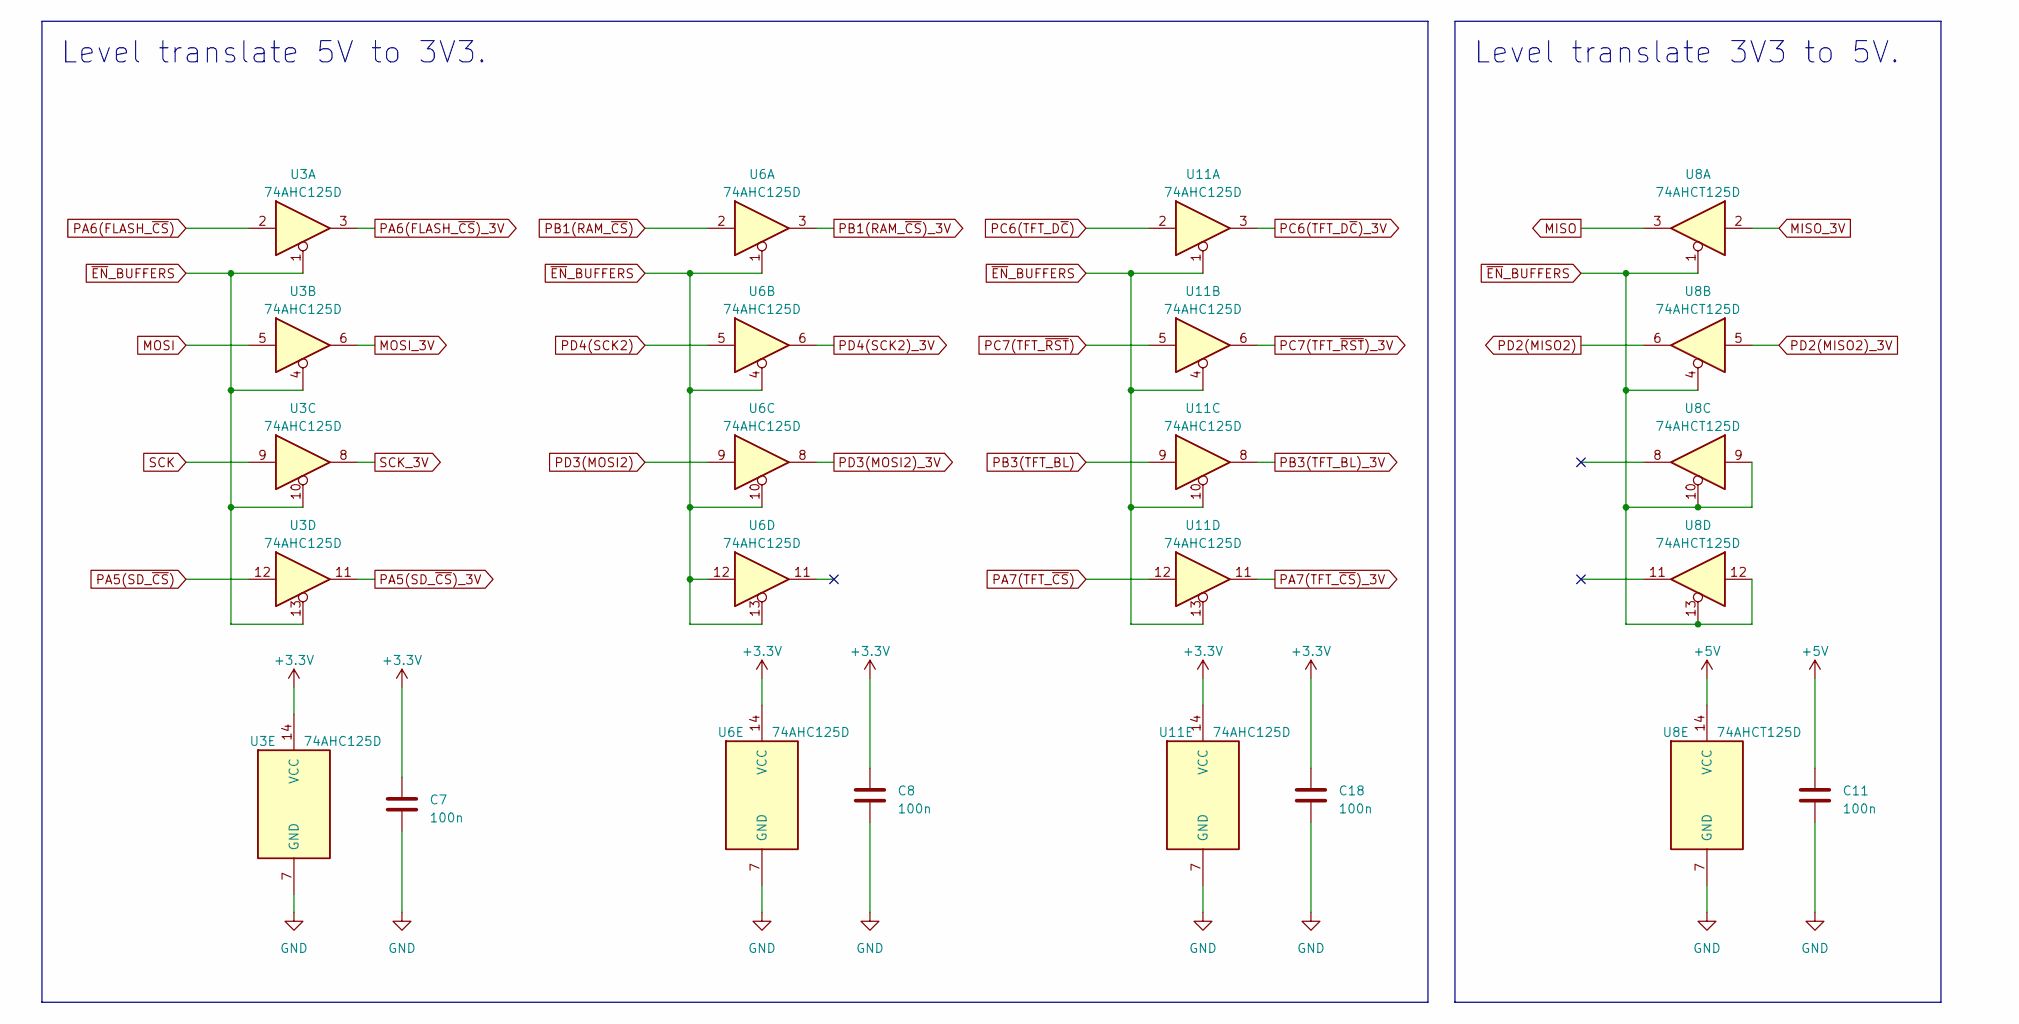
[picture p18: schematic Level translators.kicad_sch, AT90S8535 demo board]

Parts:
C7, C8, C11, C18: 100n; C_0805_2012Metric_Pad1.18x1.45mm_HandSolder
U3, U6, U11: 74AHC125D; SOIC-14_3.9x8.7mm_P1.27mm
U8: 74AHCT125D; SOIC-14_3.9x8.7mm_P1.27mm

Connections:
+3.3V: C7.1, C8.1, C18.1, U3.14 (VCC), U6.14 (VCC), U11.14 (VCC); also elsewhere on the board
MISO: U8.3; also elsewhere on the board
MISO_3V: U8.2; also elsewhere on the board
MOSI: U3.5; also elsewhere on the board
MOSI_3V: U3.6; also elsewhere on the board
PA5(SD_~CS): U3.12; also elsewhere on the board
PA5(SD_~CS)_3V: U3.11; also elsewhere on the board
PA6(FLASH_~CS): U3.2; also elsewhere on the board
PA6(FLASH_~CS)_3V: U3.3; also elsewhere on the board
PA7(TFT_~CS): U11.12; also elsewhere on the board
PA7(TFT_~CS)_3V: U11.11; also elsewhere on the board
PB3(TFT_BL): U11.9; also elsewhere on the board
PB3(TFT_BL)_3V: U11.8; also elsewhere on the board
PC6(TFT_D~C): U11.2; also elsewhere on the board
PC6(TFT_D~C)_3V: U11.3; also elsewhere on the board
PC7(TFT_~RST): U11.5; also elsewhere on the board
PC7(TFT_~RST)_3V: U11.6; also elsewhere on the board
PD2(MISO2): U8.6; also elsewhere on the board
PD2(MISO2)_3V: U8.5; also elsewhere on the board
PD3(MOSI2): U6.9; also elsewhere on the board
PD3(MOSI2)_3V: U6.8; also elsewhere on the board
PD4(SCK2): U6.5; also elsewhere on the board
PD4(SCK2)_3V: U6.6; also elsewhere on the board
SCK: U3.9; also elsewhere on the board
SCK_3V: U3.8; also elsewhere on the board

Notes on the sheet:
Level translate 5V to 3V3.
Level translate 3V3 to 5V.

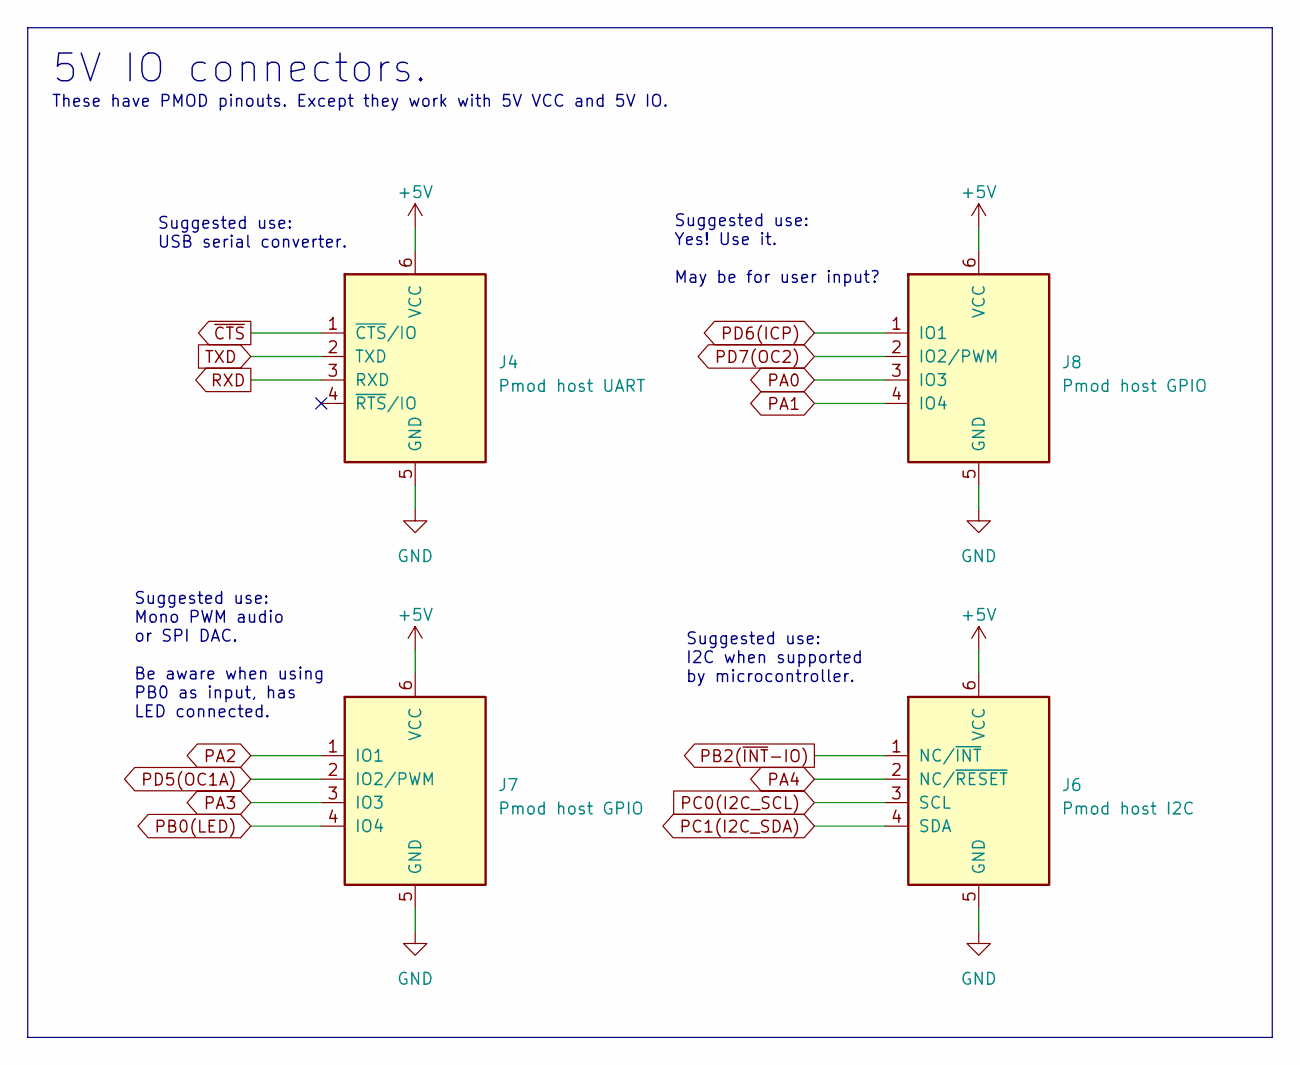
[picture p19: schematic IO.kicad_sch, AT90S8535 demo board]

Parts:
J4: Pmod host UART; PinSocket_1x06_P2.54mm_Horizontal
J6: Pmod host I2C; PinSocket_1x06_P2.54mm_Horizontal
J7, J8: Pmod host GPIO; PinSocket_1x06_P2.54mm_Horizontal

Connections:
PA0: J8.3 (IO3); also elsewhere on the board
PA1: J8.4 (IO4); also elsewhere on the board
PA2: J7.1 (IO1); also elsewhere on the board
PA3: J7.3 (IO3); also elsewhere on the board
PA4: J6.2 (NC/~RESET); also elsewhere on the board
PB0(LED): J7.4 (IO4); also elsewhere on the board
PB2(~INT-IO): J6.1 (NC/~INT); also elsewhere on the board
PC0(I2C_SCL): J6.3 (SCL); also elsewhere on the board
PC1(I2C_SDA): J6.4 (SDA); also elsewhere on the board
PD5(OC1A): J7.2 (IO2/PWM); also elsewhere on the board
PD6(ICP): J8.1 (IO1); also elsewhere on the board
PD7(OC2): J8.2 (IO2/PWM); also elsewhere on the board
RXD: J4.3 (RXD); also elsewhere on the board
TXD: J4.2 (TXD); also elsewhere on the board
~CTS: J4.1 (~CTS/IO); also elsewhere on the board

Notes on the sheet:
5V IO connectors.
Suggested use: Mono PWM audio or SPI DAC. Be aware when using PB0 as input, has LED connected.
Suggested use: USB serial converter.
These have PMOD pinouts. Except they work with 5V VCC and 5V IO.
Suggested use: Yes! Use it. May be for user input?
Suggested use: I2C when supported by microcontroller.

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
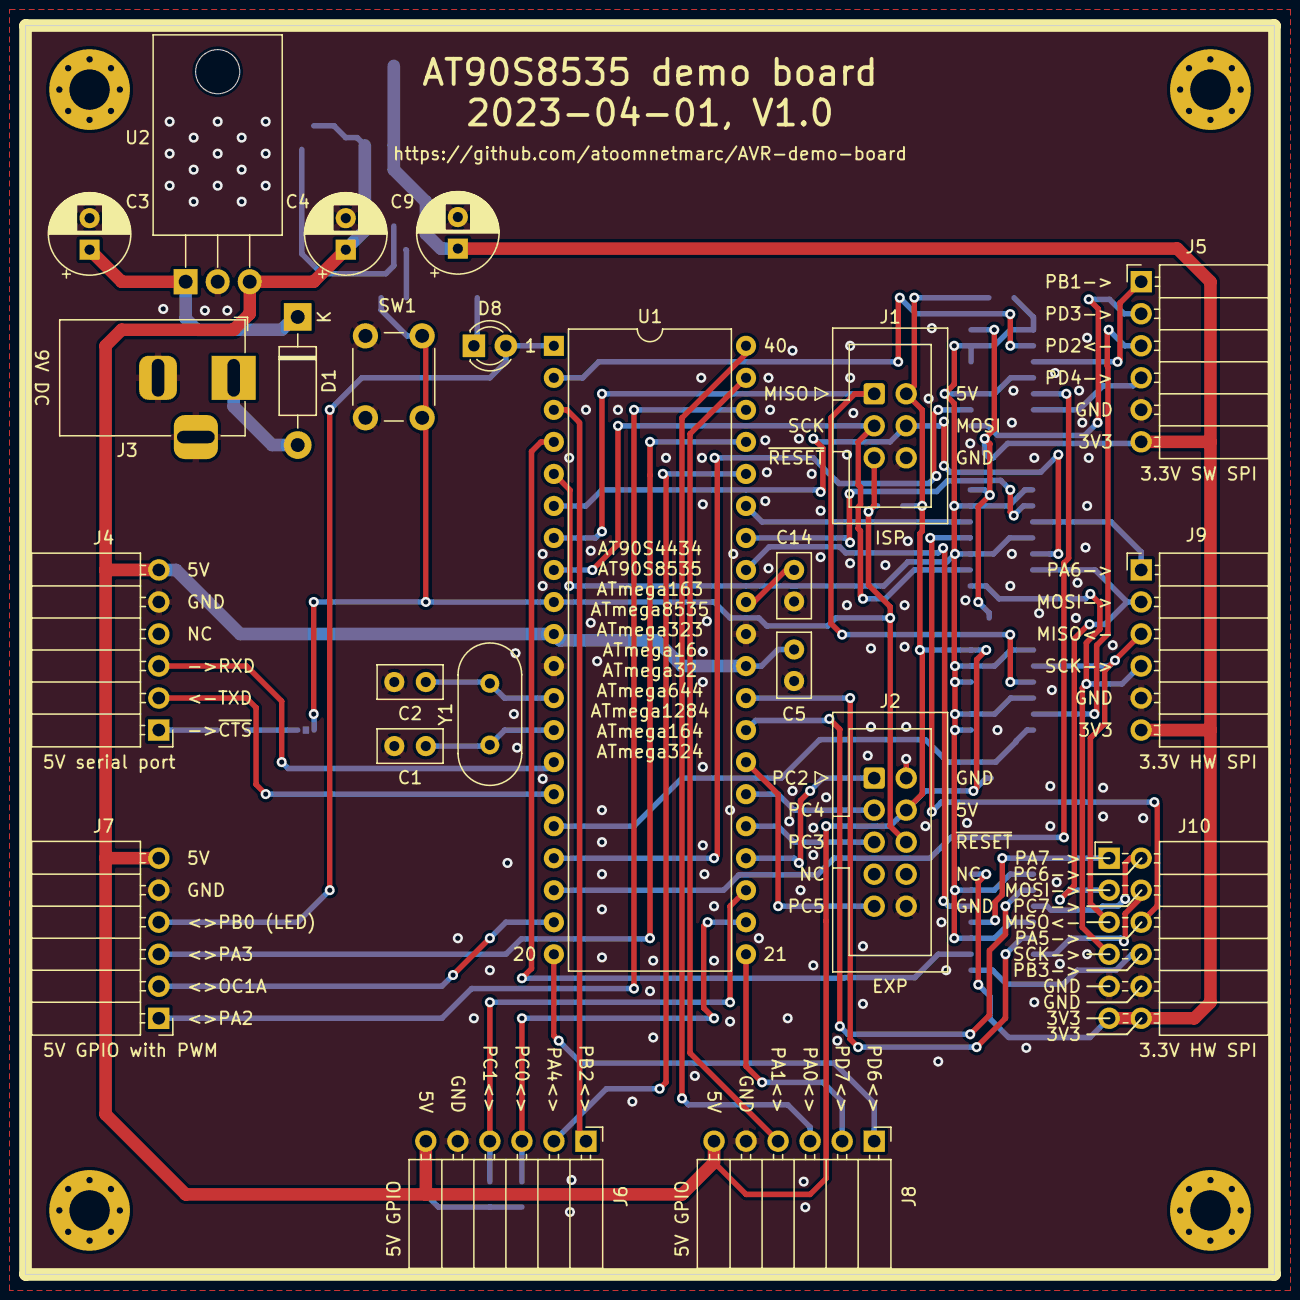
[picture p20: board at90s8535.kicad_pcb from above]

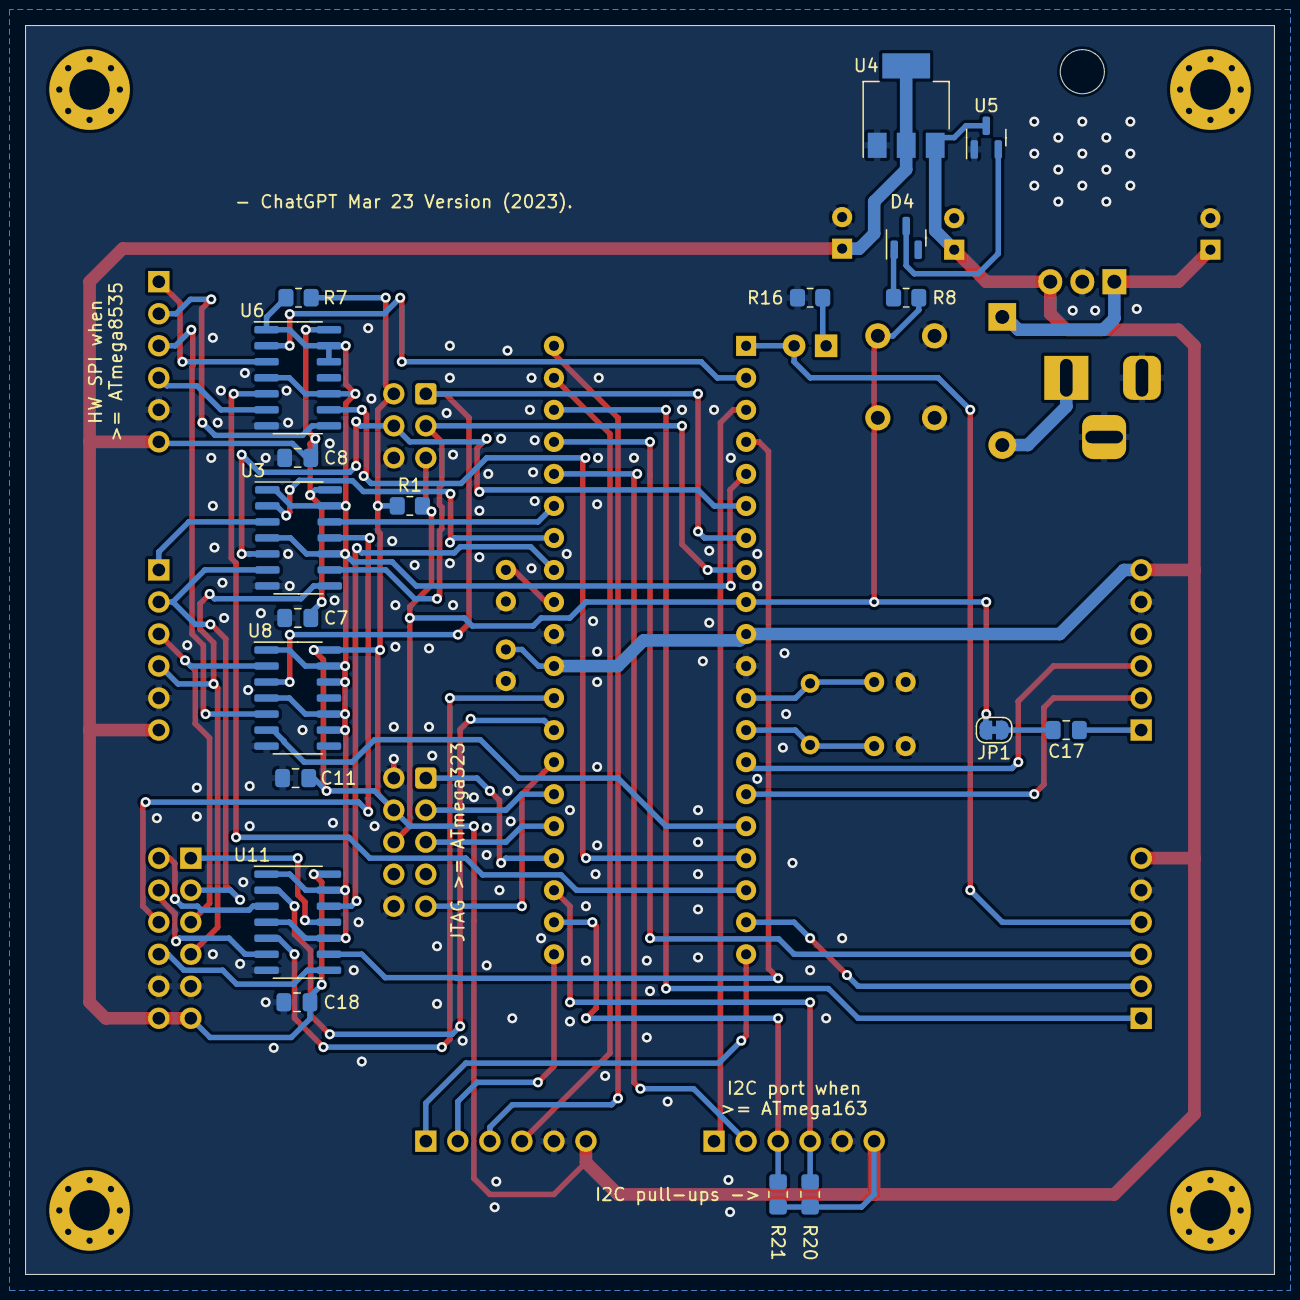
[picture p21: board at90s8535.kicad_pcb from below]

Board: 2 copper layers, 99.1 x 99.1 mm, 46 parts (19 on the bottom side), 59 nets.

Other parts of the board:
D4: BAV99; SOT-23
R8: 100R; R_0805_2012Metric_Pad1.20x1.40mm_HandSolder
U5: MAX809M; SOT-23

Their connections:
unnamed: D4.1 (K), R8.2
~RESET: R8.1; also elsewhere on the board

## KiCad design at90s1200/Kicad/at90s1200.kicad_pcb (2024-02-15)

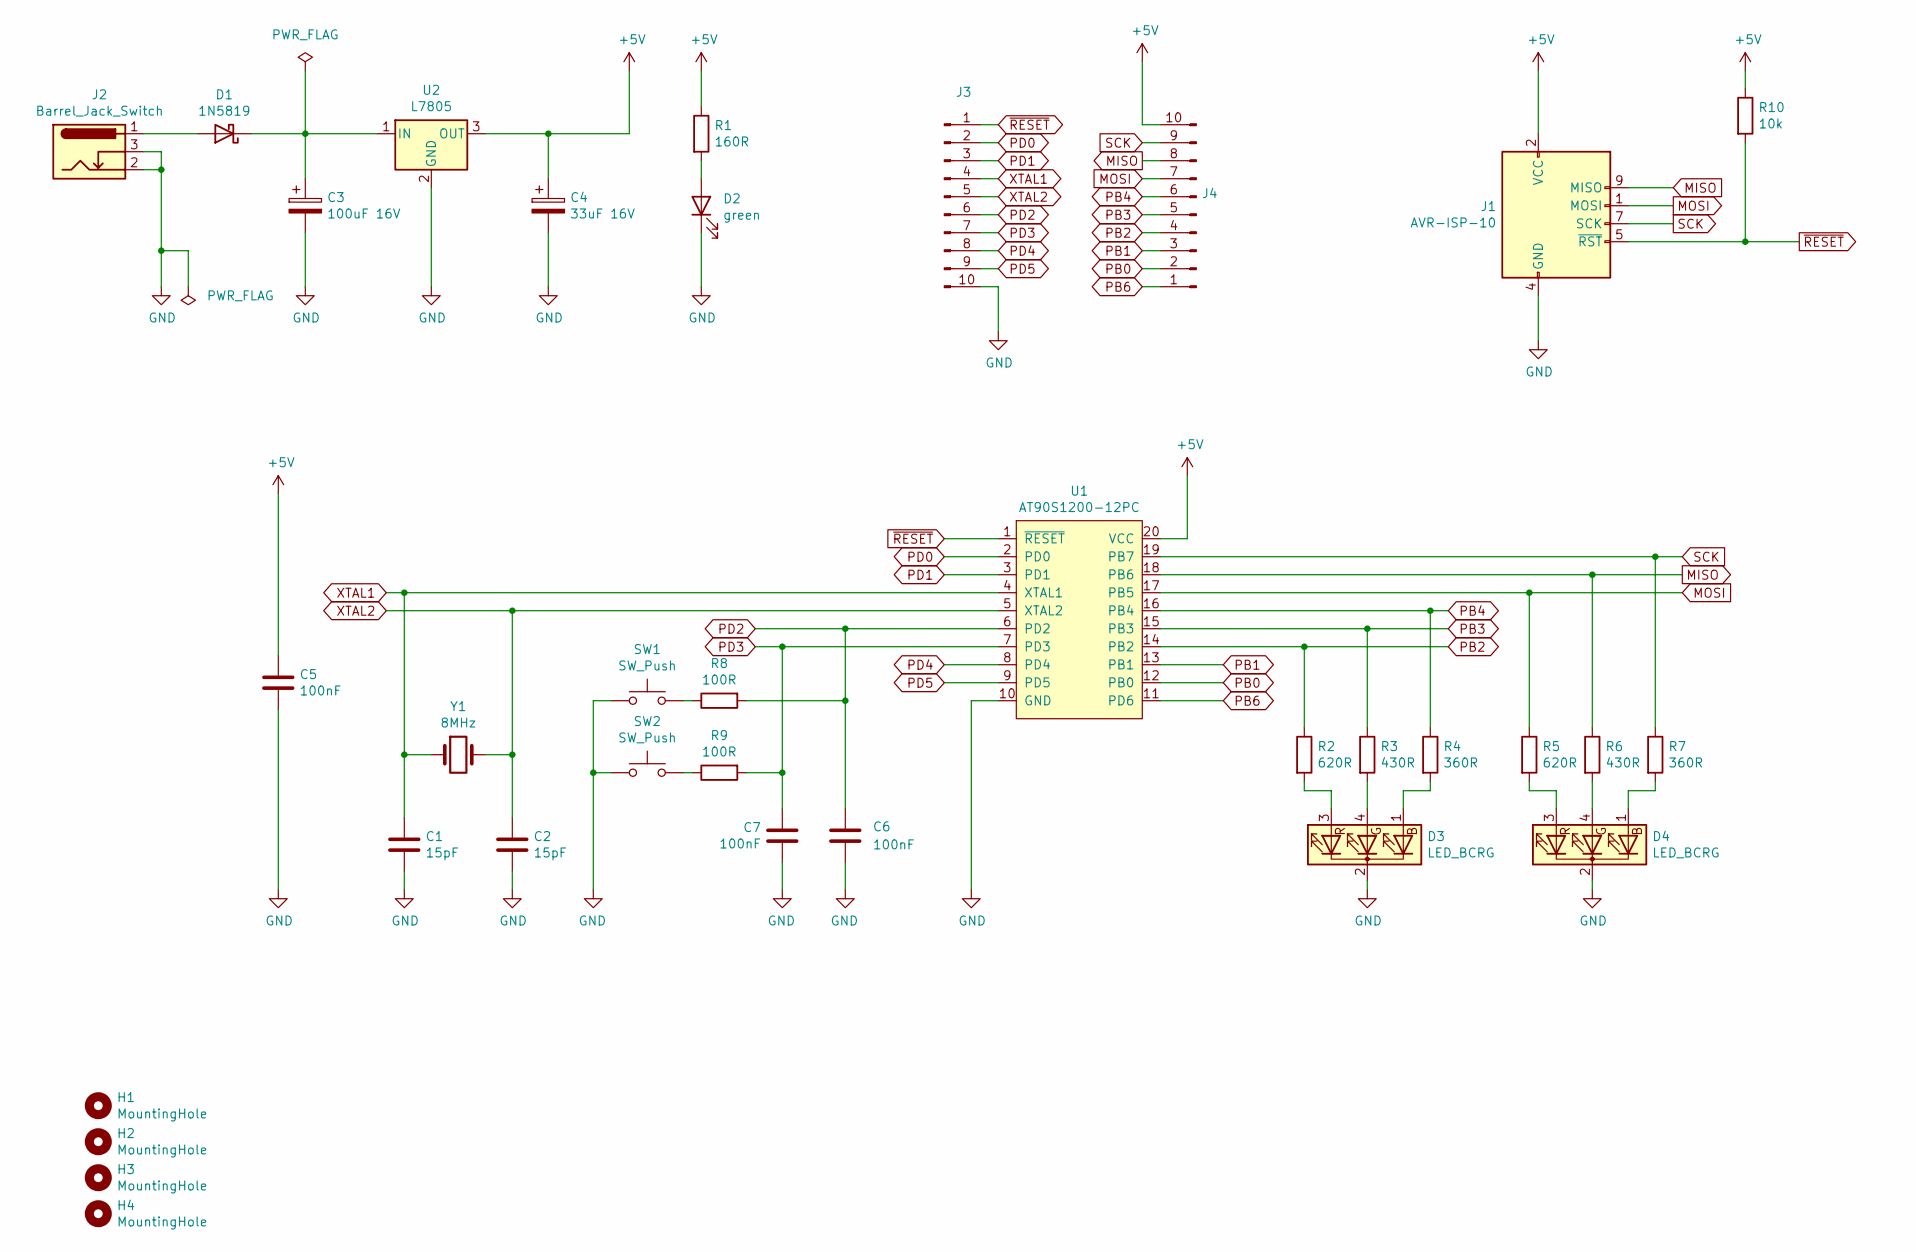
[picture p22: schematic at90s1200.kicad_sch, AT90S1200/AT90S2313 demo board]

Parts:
C1, C2: 15pF; C_Disc_D5.1mm_W3.2mm_P5.00mm
C3: 100uF 16V; CP_Radial_D6.3mm_P2.50mm
C4: 33uF 16V; CP_Radial_D6.3mm_P2.50mm
C5, C6, C7: 100nF; C_Disc_D5.1mm_W3.2mm_P5.00mm
D1: 1N5819; D_DO-15_P12.70mm_Horizontal
D2: green; LED_D5.0mm
D3, D4: LED_BCRG; LED_D5.0mm-4_RGB
H1, H2, H3, H4: MountingHole; MountingHole_3.2mm_M3_Pad_Via
J1: AVR-ISP-10; IDC-Header_2x05_P2.54mm_Vertical
J2: Barrel_Jack_Switch; BarrelJack_Horizontal
J3, J4: Conn_01x10_Male; PinHeader_1x10_P2.54mm_Vertical
R1: 160R; R_Axial_DIN0411_L9.9mm_D3.6mm_P15.24mm_Horizontal
R2, R5: 620R; R_Axial_DIN0411_L9.9mm_D3.6mm_P15.24mm_Horizontal
R3, R6: 430R; R_Axial_DIN0411_L9.9mm_D3.6mm_P15.24mm_Horizontal
R4, R7: 360R; R_Axial_DIN0411_L9.9mm_D3.6mm_P15.24mm_Horizontal
R8, R9: 100R; R_Axial_DIN0411_L9.9mm_D3.6mm_P15.24mm_Horizontal
R10: 10k; R_Axial_DIN0411_L9.9mm_D3.6mm_P15.24mm_Horizontal
SW1, SW2: SW_Push; SW_PUSH_6mm
U1: AT90S1200-12PC; DIP-20_W7.62mm_Socket_LongPads
U2: L7805; TO-220-3_Horizontal_TabDown
Y1: 8MHz; Crystal_HC49-U_Vertical

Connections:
+5V: C4.1, C5.1, J1.2 (VCC), J4.10, R1.1, R10.1, U1.20 (VCC), U2.3 (OUT)
GND: C1.2, C2.2, C3.2, C4.2, C5.2, C6.2, C7.2, D2.1 (K), D3.2 (K), D4.2 (K), J1.4 (GND), J1.6 (GND), J1.8 (GND), J1.10 (GND), J2.2, J2.3, J3.10, SW1.2, SW2.2, U1.10 (GND), U2.2 (GND)
MISO: J1.9 (MISO), J4.8, R6.1, U1.18 (PB6)
MOSI: J1.1 (MOSI), J4.7, R5.1, U1.17 (PB5)
unnamed: D1.2 (A), J2.1
unnamed: C3.1, D1.1 (K), U2.1 (IN)
unnamed: D2.2 (A), R1.2
unnamed: D3.1 (BA), R4.2
unnamed: D3.4 (GA), R3.2
unnamed: D3.3 (RA), R2.2
unnamed: D4.1 (BA), R7.2
unnamed: D4.4 (GA), R6.2
unnamed: D4.3 (RA), R5.2
unnamed: R8.1, SW1.1
unnamed: R9.1, SW2.1
PB0: J4.2, U1.12 (PB0)
PB1: J4.3, U1.13 (PB1)
PB2: J4.4, R2.1, U1.14 (PB2)
PB3: J4.5, R3.1, U1.15 (PB3)
PB4: J4.6, R4.1, U1.16 (PB4)
PB6: J4.1, U1.11 (PD6)
PD0: J3.2, U1.2 (PD0)
PD1: J3.3, U1.3 (PD1)
PD2: C6.1, J3.6, R8.2, U1.6 (PD2)
PD3: C7.1, J3.7, R9.2, U1.7 (PD3)
PD4: J3.8, U1.8 (PD4)
PD5: J3.9, U1.9 (PD5)
SCK: J1.7 (SCK), J4.9, R7.1, U1.19 (PB7)
XTAL1: C1.1, J3.4, U1.4 (XTAL1), Y1.1
XTAL2: C2.1, J3.5, U1.5 (XTAL2), Y1.2
~RESET: J1.5 (~RST), J3.1, R10.2, U1.1 (~RESET)

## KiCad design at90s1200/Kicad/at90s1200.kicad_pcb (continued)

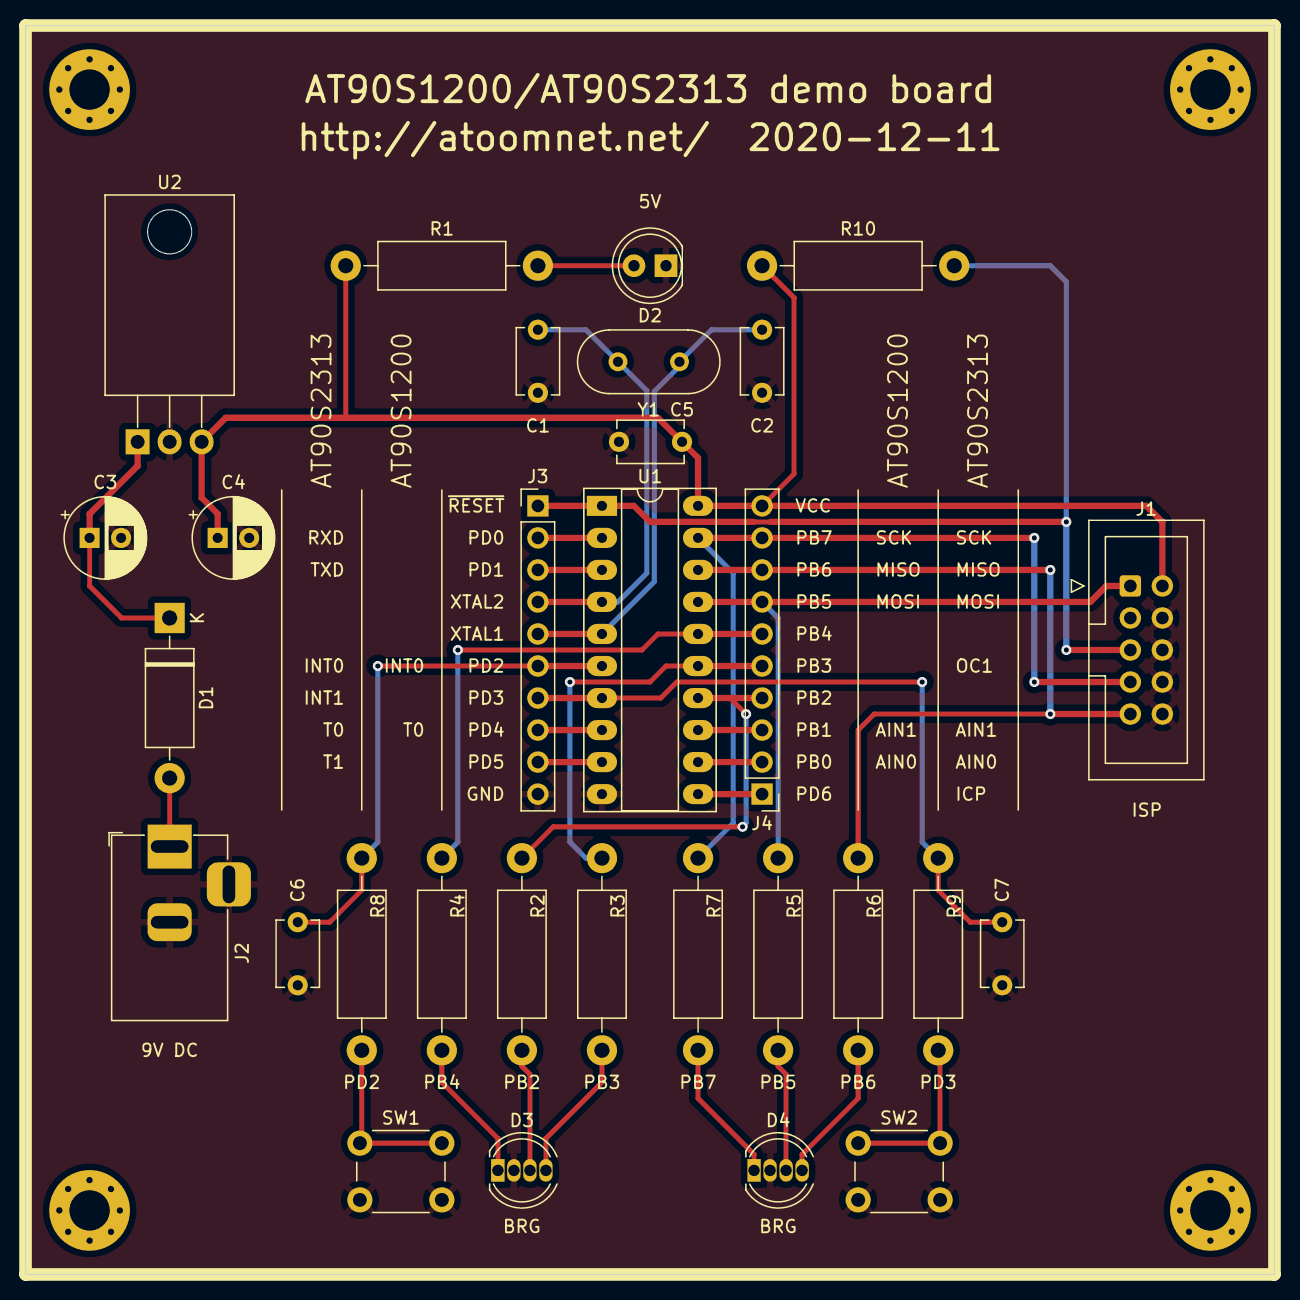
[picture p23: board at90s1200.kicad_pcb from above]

Board: 2 copper layers, 99.1 x 99.1 mm, 34 parts (0 on the bottom side), 31 nets.

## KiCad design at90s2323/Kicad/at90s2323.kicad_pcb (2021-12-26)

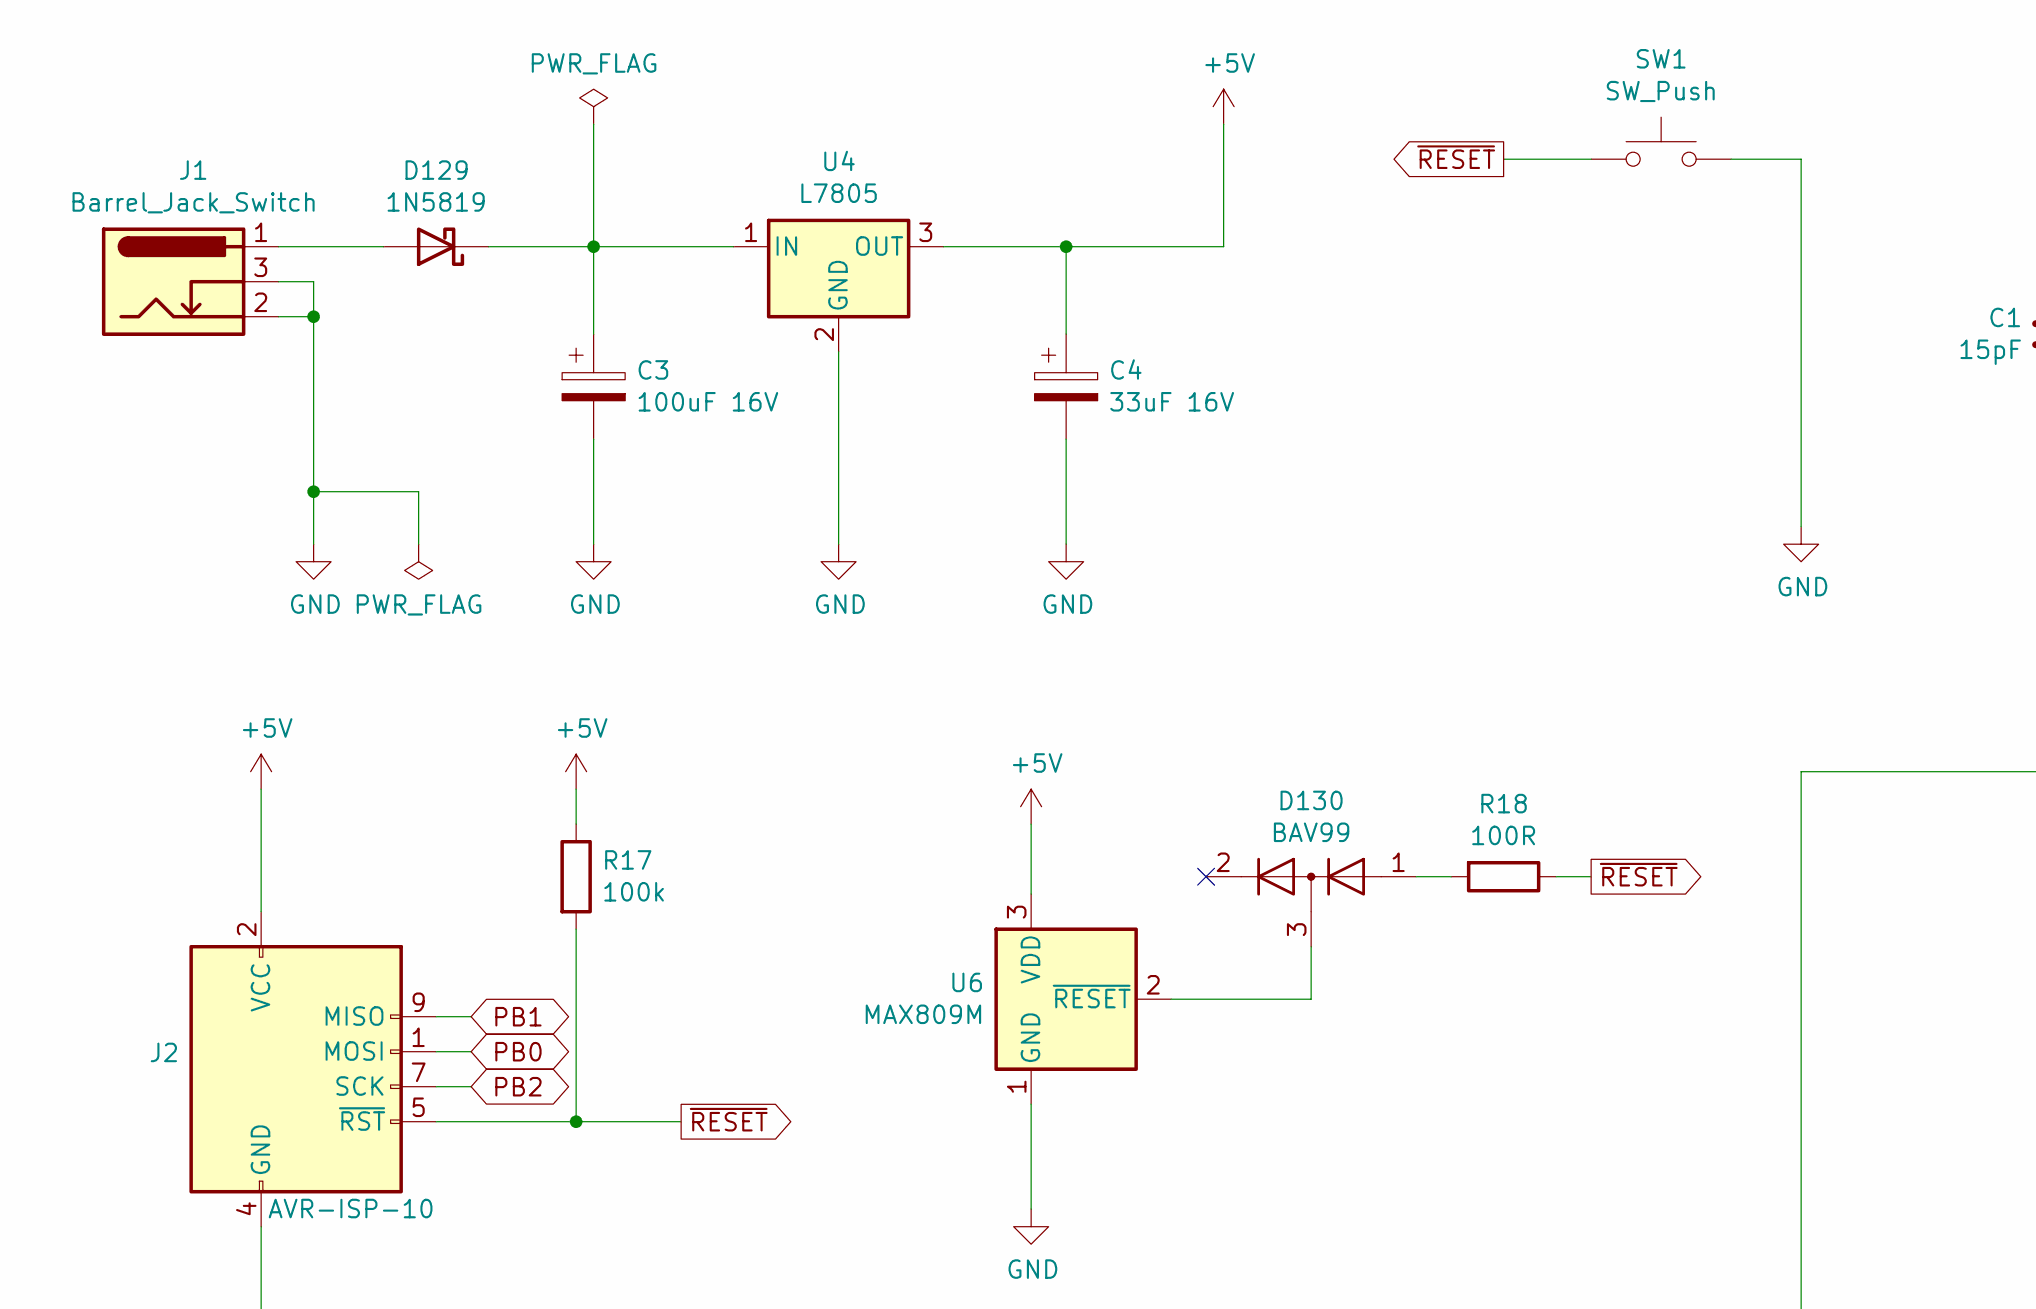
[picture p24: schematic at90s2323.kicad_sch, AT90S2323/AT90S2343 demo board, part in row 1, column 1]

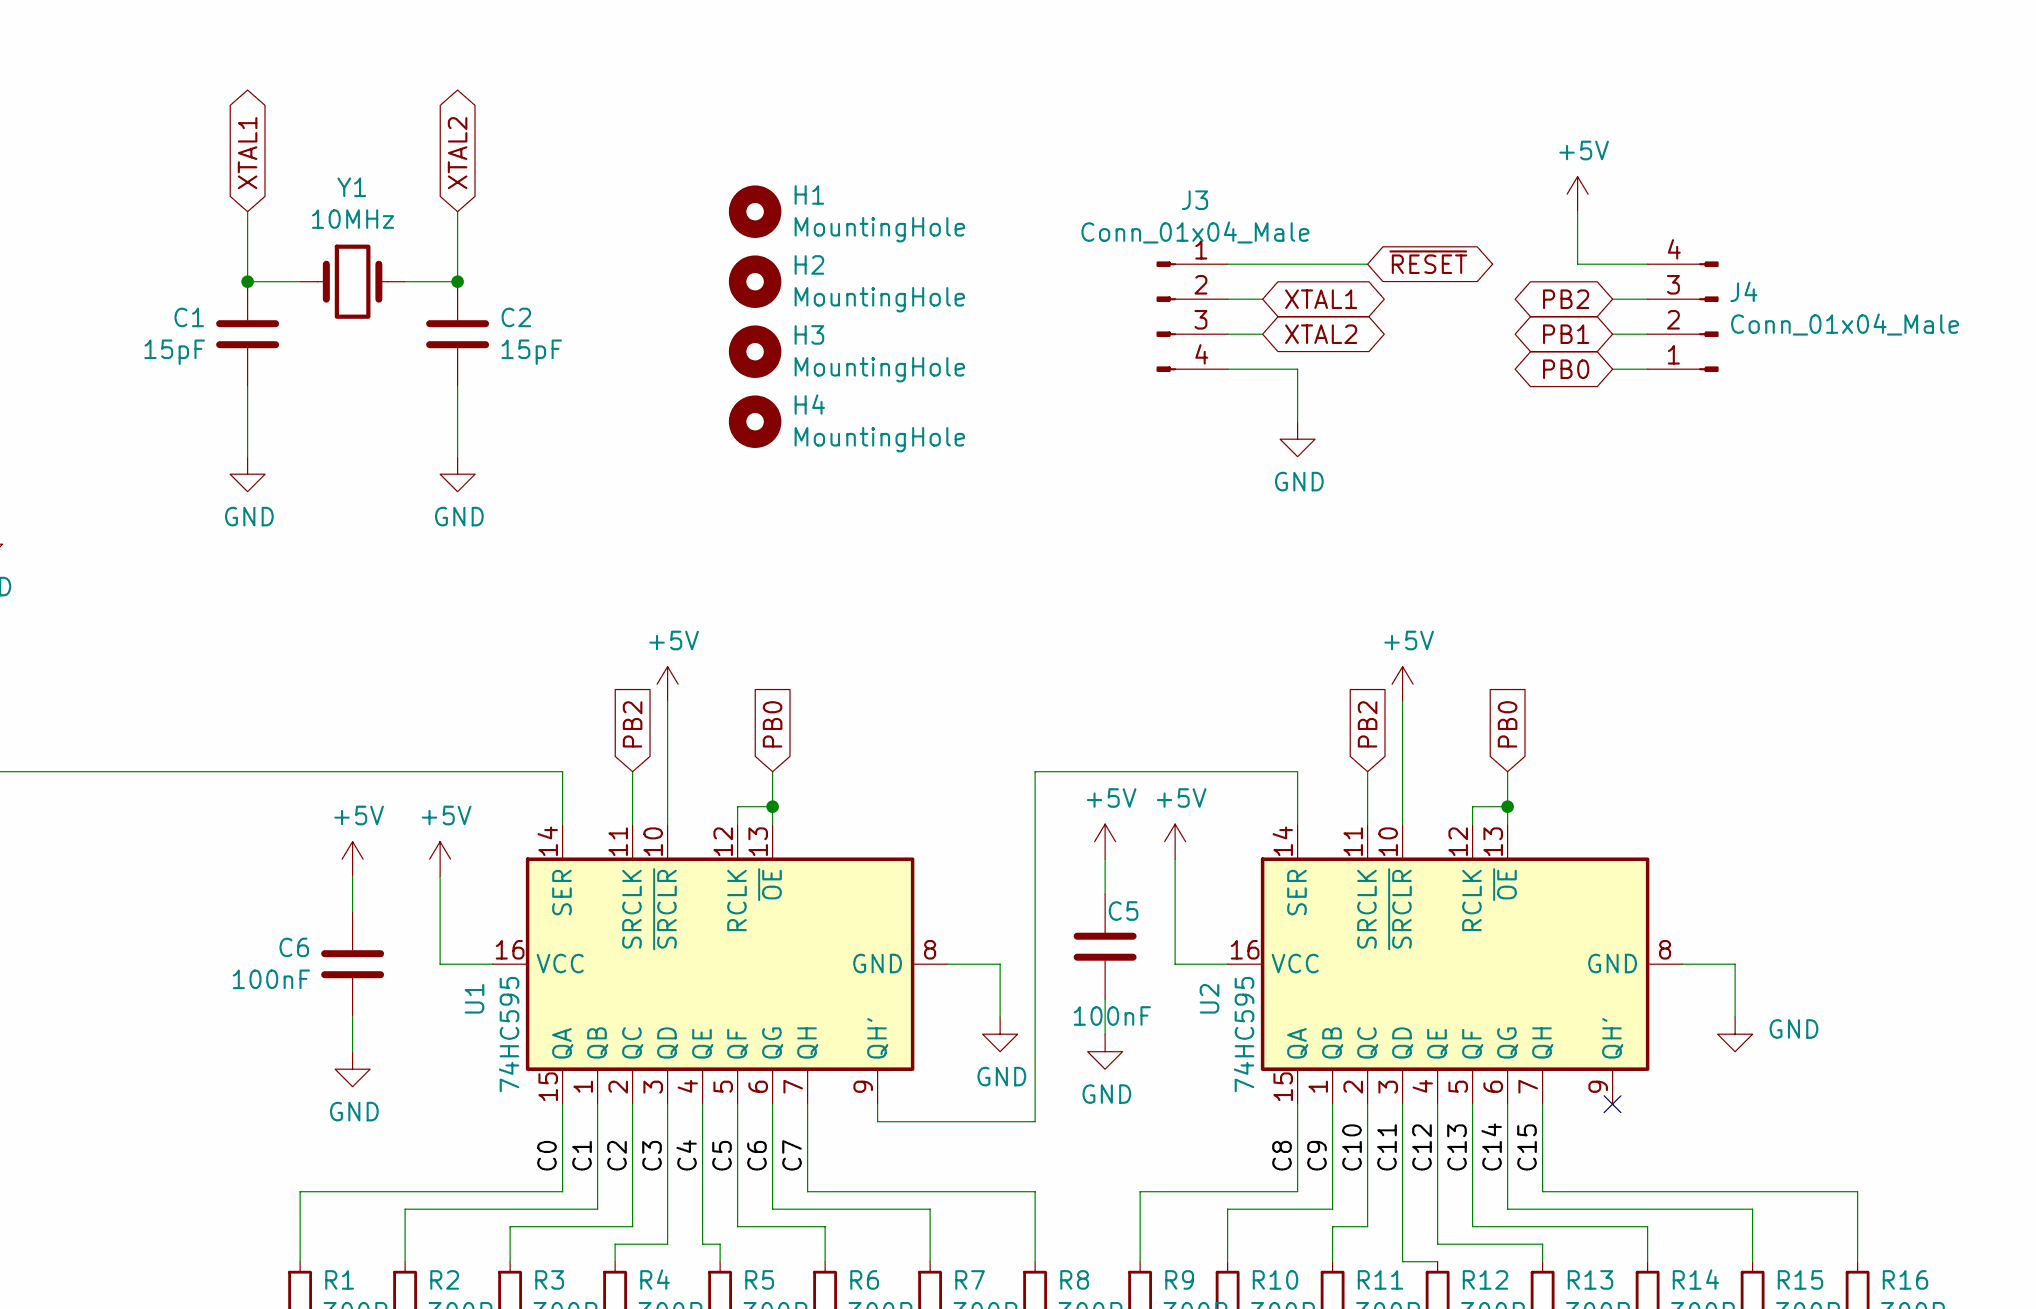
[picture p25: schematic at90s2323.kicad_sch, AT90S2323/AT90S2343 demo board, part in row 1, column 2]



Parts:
C1, C2: 15pF; C_Disc_D5.1mm_W3.2mm_P5.00mm
C3: 100uF 16V; CP_Radial_D6.3mm_P2.50mm
C4: 33uF 16V; CP_Radial_D6.3mm_P2.50mm
C5, C6, C7: 100nF; C_Disc_D5.1mm_W3.2mm_P5.00mm
D1, D2, D3, D4, D5, D6, D7, D8, D9, D10, D11, D12, D13, D14, D15, D16, D17, D18, D19, D20, D21, D22, D23, D24, D25, D26, D27, D28, D29, D30, D31, D32, D33, D34, D35, D36, D37, D38, D39, D40, D41, D42, D43, D44, D45, D46, D47, D48, D49, D50, D51, D52, D53, D54, D55, D56, D57, D58, D59, D60, D61, D62, D63, D64, D65, D66, D67, D68, D69, D70, D71, D72, D73, D74, D75, D76, D77, D78, D79, D80, D81, D82, D83, D84, D85, D86, D87, D88, D89, D90, D91, D92, D93, D94, D95, D96, D97, D98, D99, D100, D101, D102, D103, D104, D105, D106, D107, D108, D109, D110, D111, D112, D113, D114, D115, D116, D117, D118, D119, D120, D121, D122, D123, D124, D125, D126, D127, D128: blue opaque; LED_D3.0mm_IRGrey
D129: 1N5819; D_DO-15_P5.08mm_Vertical_KathodeUp
D130: BAV99; SOT-23
H1, H2, H3, H4: MountingHole; MountingHole_3.2mm_M3_Pad_Via
J1: Barrel_Jack_Switch; BarrelJack_Horizontal
J2: AVR-ISP-10; IDC-Header_2x05_P2.54mm_Vertical
J3, J4: Conn_01x04_Male; PinHeader_1x04_P2.54mm_Vertical
R1, R2, R3, R4, R5, R6, R7, R8, R9, R10, R11, R12, R13, R14, R15, R16: 300R; R_Axial_DIN0207_L6.3mm_D2.5mm_P2.54mm_Vertical
R17: 100k; R_Axial_DIN0207_L6.3mm_D2.5mm_P10.16mm_Horizontal
R18: 100R; R_0805_2012Metric_Pad1.20x1.40mm_HandSolder
SW1: SW_Push; SW_PUSH_6mm
U1, U2: 74HC595; DIP-16_W7.62mm
U3: TPIC6B595; DIP-20_W7.62mm_LongPads
U4: L7805; TO-220-3_Horizontal_TabDown
U5: AT90S2323; DIP-8_W7.62mm
U6: MAX809M; SOT-23
Y1: 10MHz; Crystal_HC49-U_Vertical

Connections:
+5V: C4.1, C5.1, C6.1, C7.1, J2.2 (VCC), J4.4, R17.1, U1.10 (~SRCLR), U1.16 (VCC), U2.10 (~SRCLR), U2.16 (VCC), U3.2 (VCC), U3.8 (~SRCLR), U4.3 (OUT), U5.8 (VCC), U6.3 (VDD)
/C0: R1.1, U1.15 (QA)
/C1: R2.1, U1.1 (QB)
/C2: R3.1, U1.2 (QC)
/C3: R4.1, U1.3 (QD)
/C4: R5.1, U1.4 (QE)
/C5: R6.1, U1.5 (QF)
/C6: R7.1, U1.6 (QG)
/C7: R8.1, U1.7 (QH)
/C8: R9.1, U2.15 (QA)
/C9: R10.1, U2.1 (QB)
/C10: R11.1, U2.2 (QC)
/C11: R12.1, U2.3 (QD)
/C12: R13.1, U2.4 (QE)
/C13: R14.1, U2.5 (QF)
/C14: R15.1, U2.6 (QG)
/C15: R16.1, U2.7 (QH)
/R0: D1.1 (K), D2.1 (K), D3.1 (K), D4.1 (K), D5.1 (K), D6.1 (K), D7.1 (K), D8.1 (K), D9.1 (K), D10.1 (K), D11.1 (K), D12.1 (K), D13.1 (K), D14.1 (K), D15.1 (K), D16.1 (K), U3.4 (DRAIN0)
/R1: D17.1 (K), D18.1 (K), D19.1 (K), D20.1 (K), D21.1 (K), D22.1 (K), D23.1 (K), D24.1 (K), D25.1 (K), D26.1 (K), D27.1 (K), D28.1 (K), D29.1 (K), D30.1 (K), D31.1 (K), D32.1 (K), U3.5 (DRAIN1)
/R2: D33.1 (K), D34.1 (K), D35.1 (K), D36.1 (K), D37.1 (K), D38.1 (K), D39.1 (K), D40.1 (K), D41.1 (K), D42.1 (K), D43.1 (K), D44.1 (K), D45.1 (K), D46.1 (K), D47.1 (K), D48.1 (K), U3.6 (DRAIN2)
/R3: D49.1 (K), D50.1 (K), D51.1 (K), D52.1 (K), D53.1 (K), D54.1 (K), D55.1 (K), D56.1 (K), D57.1 (K), D58.1 (K), D59.1 (K), D60.1 (K), D61.1 (K), D62.1 (K), D63.1 (K), D64.1 (K), U3.7 (DRAIN3)
/R4: D65.1 (K), D66.1 (K), D67.1 (K), D68.1 (K), D69.1 (K), D70.1 (K), D71.1 (K), D72.1 (K), D73.1 (K), D74.1 (K), D75.1 (K), D76.1 (K), D77.1 (K), D78.1 (K), D79.1 (K), D80.1 (K), U3.14 (DRAIN4)
/R5: D81.1 (K), D82.1 (K), D83.1 (K), D84.1 (K), D85.1 (K), D86.1 (K), D87.1 (K), D88.1 (K), D89.1 (K), D90.1 (K), D91.1 (K), D92.1 (K), D93.1 (K), D94.1 (K), D95.1 (K), D96.1 (K), U3.15 (DRAIN5)
/R6: D97.1 (K), D98.1 (K), D99.1 (K), D100.1 (K), D101.1 (K), D102.1 (K), D103.1 (K), D104.1 (K), D105.1 (K), D106.1 (K), D107.1 (K), D108.1 (K), D109.1 (K), D110.1 (K), D111.1 (K), D112.1 (K), U3.16 (DRAIN6)
/R7: D113.1 (K), D114.1 (K), D115.1 (K), D116.1 (K), D117.1 (K), D118.1 (K), D119.1 (K), D120.1 (K), D121.1 (K), D122.1 (K), D123.1 (K), D124.1 (K), D125.1 (K), D126.1 (K), D127.1 (K), D128.1 (K), U3.17 (DRAIN7)
GND: C1.2, C2.2, C3.2, C4.2, C5.2, C6.2, C7.2, J1.2, J1.3, J2.4 (GND), J2.6 (GND), J2.8 (GND), J2.10 (GND), J3.4, SW1.2, U1.8 (GND), U2.8 (GND), U3.1 (NC), U3.10 (GND), U3.11 (GND), U3.19 (GND), U3.20 (NC), U4.2 (GND), U5.4 (GND), U6.1 (GND)
unnamed: C3.1, D129.1 (K), U4.1 (IN)
unnamed: D1.2 (A), D17.2 (A), D33.2 (A), D49.2 (A), D65.2 (A), D81.2 (A), D97.2 (A), D113.2 (A), R1.2
unnamed: D10.2 (A), D26.2 (A), D42.2 (A), D58.2 (A), D74.2 (A), D90.2 (A), D106.2 (A), D122.2 (A), R10.2
unnamed: D4.2 (A), D20.2 (A), D36.2 (A), D52.2 (A), D68.2 (A), D84.2 (A), D100.2 (A), D116.2 (A), R4.2
unnamed: D5.2 (A), D21.2 (A), D37.2 (A), D53.2 (A), D69.2 (A), D85.2 (A), D101.2 (A), D117.2 (A), R5.2
unnamed: D6.2 (A), D22.2 (A), D38.2 (A), D54.2 (A), D70.2 (A), D86.2 (A), D102.2 (A), D118.2 (A), R6.2
unnamed: D7.2 (A), D23.2 (A), D39.2 (A), D55.2 (A), D71.2 (A), D87.2 (A), D103.2 (A), D119.2 (A), R7.2
unnamed: D8.2 (A), D24.2 (A), D40.2 (A), D56.2 (A), D72.2 (A), D88.2 (A), D104.2 (A), D120.2 (A), R8.2
unnamed: D9.2 (A), D25.2 (A), D41.2 (A), D57.2 (A), D73.2 (A), D89.2 (A), D105.2 (A), D121.2 (A), R9.2
unnamed: D11.2 (A), D27.2 (A), D43.2 (A), D59.2 (A), D75.2 (A), D91.2 (A), D107.2 (A), D123.2 (A), R11.2
unnamed: D12.2 (A), D28.2 (A), D44.2 (A), D60.2 (A), D76.2 (A), D92.2 (A), D108.2 (A), D124.2 (A), R12.2
unnamed: D13.2 (A), D29.2 (A), D45.2 (A), D61.2 (A), D77.2 (A), D93.2 (A), D109.2 (A), D125.2 (A), R13.2
unnamed: D14.2 (A), D30.2 (A), D46.2 (A), D62.2 (A), D78.2 (A), D94.2 (A), D110.2 (A), D126.2 (A), R14.2
unnamed: D15.2 (A), D31.2 (A), D47.2 (A), D63.2 (A), D79.2 (A), D95.2 (A), D111.2 (A), D127.2 (A), R15.2
unnamed: D16.2 (A), D32.2 (A), D48.2 (A), D64.2 (A), D80.2 (A), D96.2 (A), D112.2 (A), D128.2 (A), R16.2
unnamed: D2.2 (A), D18.2 (A), D34.2 (A), D50.2 (A), D66.2 (A), D82.2 (A), D98.2 (A), D114.2 (A), R2.2
unnamed: D3.2 (A), D19.2 (A), D35.2 (A), D51.2 (A), D67.2 (A), D83.2 (A), D99.2 (A), D115.2 (A), R3.2
unnamed: D129.2 (A), J1.1
unnamed: D130.1 (K), R18.2
unnamed: D130.3 (K), U6.2 (~RESET)
unnamed: U1.9 (QH'), U2.14 (SER)
unnamed: U1.14 (SER), U3.18 (SER_OUT)
PB0: J2.1 (MOSI), J4.1, U1.12 (RCLK), U1.13 (~OE), U2.12 (RCLK), U2.13 (~OE), U3.9 (~G), U3.12 (RCLK), U5.5 (MOSI/PB0)
PB1: J2.9 (MISO), J4.2, U3.3 (SER_IN), U5.6 (INT0/MISO/PB1)
PB2: J2.7 (SCK), J4.3, U1.11 (SRCLK), U2.11 (SRCLK), U3.13 (SRCK), U5.7 (T0/SCK/PB2)
XTAL1: C1.1, J3.2, U5.2 (XTAL1), Y1.1
XTAL2: C2.1, J3.3, U5.3 (XTAL2), Y1.2
~RESET: J2.5 (~RST), J3.1, R17.2, R18.1, SW1.1, U5.1 (~RESET)



Board: 2 copper layers, 99.1 x 99.1 mm, 171 parts (3 on the bottom side), 54 nets.

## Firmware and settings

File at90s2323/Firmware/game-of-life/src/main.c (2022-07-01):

/*

Copyright 2021-2022 Marc Ketel
SPDX-License-Identifier: Apache-2.0

*/

#include <avr/interrupt.h>
#include <avr/io.h>
#include <avr/wdt.h>

#include <util/delay.h>

#include "io.h"
#include "main.h"
#include "mcu.h"
#include "gameoflife.h"
#include "shift.h"

//array representing the 16x8 LED matrix
volatile uint8_t matrix[MATRIX_WIDTH];

#define EV_1MS 1
volatile uint8_t event = 0;

void setup(void)
{
    //Enable watchdog
    wdt_enable(WDTO_500MS);

    //All IO is output.
    DATA_DDR = 1;
    SCK_DDR = 1;
    OE_DDR = 1;

    //Configure timer0
    MCU_TCCR0 |= _BV(CS00) | _BV(CS01); //clk/64
    TIMSK |= _BV(TOIE0);

    //Enable interrupts
    sei();

    gameSetup();
}

ISR(MCU_TIMER0_OVF_vect)
{
    uint8_t clkdiv = 64;
    uint16_t timerHz = 1000;
    TCNT0 = 256 - (F_CPU / clkdiv / timerHz);

    //Output to LED matrix
    shift();

    //Signal that 1ms has passed.
    event |= EV_1MS;
}

void loop(void)
{
    wdt_reset();

    while (event == 0)
    {
        //Intensively do nothing while waiting for some event.
    }

    if (event & EV_1MS)
    {
        event &= ~EV_1MS;

        gameLoop();
    }
}

__attribute__((OS_main)) int main(void)
{
    setup();

    for (;;)
    {
        loop();
    }
}

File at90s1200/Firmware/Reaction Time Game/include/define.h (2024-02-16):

/*

Copyright 2024 Marc Ketel
SPDX-License-Identifier: Apache-2.0

*/

#ifndef define_H
#define define_H

#define LEDPORT PORTB
#define LEDPIN  PINB
#define LEDDDR  DDRB
#define LED1R   PB2
#define LED1G   PB3
#define LED1B   PB4
#define LED2R   PB5
#define LED2G   PB6
#define LED2B   PB7

#define BUTTONDDR DDRD
#define BUTTONPORT PORTD
#define BUTTONPIN PIND
#define BUTTON1 PD2
#define BUTTON2 PD3

#define LOOPDEBUGDDR  DDRD
#define LOOPDEBUGPORT PORTD
#define LOOPDEBUG     PD0

#define TIMERDEBUGDDR  DDRD
#define TIMERDEBUGPORT PORTD
#define TIMERDEBUG     PD1

// Registers shared by ISR and program.
#define event r16
#define random r0

// Registers used by program.
#define temp1 r17
#define temp2 r18
#define game_state_current r1
#define game_state_next r2
#define game_timer r3

// Registers used by ISR.
#define isr_S r4
#define isr_temp r19
#define isr_button r20
#define isr_counter_1ms r5
#define isr_counter_100ms r6

// List of events that could happen at the same time in the event register.
#define EV_1ms 0
#define EV_100ms 1
#define EV_BUTTON1 2
#define EV_BUTTON2 3

// List of game states
#define GS_START 0
#define GS_WAIT 1
#define GS_LED_CHANGE 2
#define GS_PLAYER_WAIT 3
#define GS_WIN_NOBODY 4
#define GS_WIN_PLAYER1 5
#define GS_WIN_PLAYER2 6
#define GS_WIN_BOTH 7
#define GS_END 8
#define GS_END_WAIT 9

#endif

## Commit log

2021-11-12 Add VSCode project to program at90s1200 in assembler.
2021-11-13 Add 3d printable presentation stand for demo board.
    [presentation stand.FCStd, presentation stand.step, presentation stand.stl]
2021-12-26 Convert to Kicad 6
    [at90s1200.kicad_pcb, at90s1200.kicad_sch, at90s1200.sch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]
2021-12-26 Kicad 6 ERC fixes.
    [at90s1200.kicad_pcb, at90s1200.kicad_sch, at90s2323.kicad_pcb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]
2023-03-25 Added ATmega8515 to pin overview.
2023-04-07 Add AT90S8535 demo board.
    [IO.kicad_sch, Level translators.kicad_sch, Power.kicad_sch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]
2023-04-18 Exclude mounting holes from BOM.
    [at90s8535.kicad_pcb, at90s8535.kicad_sch]
2023-04-18 Exclude solder jumper from BOM.
    [Programming debug.kicad_sch, at90s8535.kicad_pcb]
2023-05-20 Change LED R from 1k to 10k.
    [Programming debug.kicad_sch, at90s8535.kicad_pcb]
2023-05-20 AT90S8535 board has been made real.
2024-01-13 Correct part number for 5V to 3V level translation.
    [IO.kicad_sch, Level translators.kicad_sch, Power.kicad_sch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]
2024-02-08 Add PDF schematic.
2024-02-12 Add Microchip Studio project file for assembly debug.
2024-02-15 Redraw schematic to contain actual schema instead of only labels. Kicad upgrade. No change to board.
    [at90s1200-B_Cu.gbl, at90s1200-B_Cu.gbr, at90s1200-B_Mask.gbr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]
2024-02-16 Add 'Reaction Time Game' for at90s1200 and pin-compatible parts.
2024-10-04 No change. Upgrade to Kicad 8.
    [IO.kicad_sch, Level translators.kicad_sch, Power.kicad_sch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]

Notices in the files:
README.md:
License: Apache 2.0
